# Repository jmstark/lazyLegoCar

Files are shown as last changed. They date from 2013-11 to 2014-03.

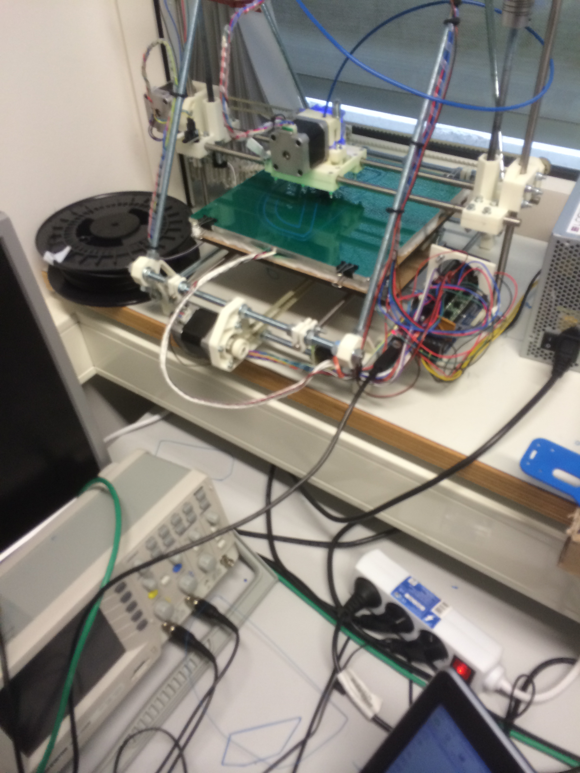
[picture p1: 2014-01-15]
Fotos/IMG_1469.JPG

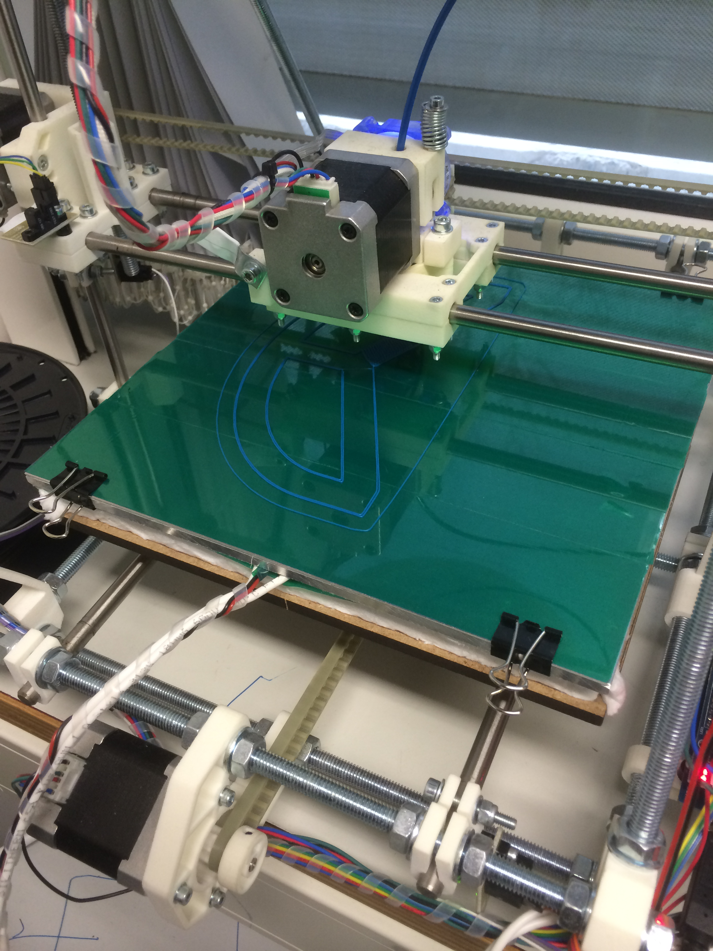
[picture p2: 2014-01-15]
Fotos/IMG_1471.JPG

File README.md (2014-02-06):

lazyLegoCar
===========

Lego car with basic collision avoidance/ path planning

Setup:
===========

Starting the car:
===========

Prerequisite:
Install the App "HelloWorld" (should be renamed in the future) on your smartphone: The compiled app is located in the github repository. The relative path is HelloWorld/bin/HelloWorld.apk. So either clone the git repository and pick the app from your file system, or download it directly from https://github.com/jmstark/lazyLegoCar/raw/master/HelloWorld/bin/HelloWorld.apk . Put the .apk-file on your smartphone and install it (Foreign app sources have to be enabled to allow this).
On your smartphone, the app is named "LegoCarControl".

If everything is compiled and in place (as is the case after the final presentation), to start the car you have to:

1. Turn on the battery.

2. Connect the ethernet port of the raspberry to your pc. Otherwise, it will not start. But you do not need to send anything over the ethernet connection.

3. The raspberry needs power over Micro-USB (a normal charging cable for a smartphone is sufficient). Plug it into your PC.

4. After about 30 seconds, the servo of the back laser should start to move, which indicates the start of the program. So you can connect now via WIFI.

5. On your smartphone, enable WIFI and connect to the WLAN with the SSID "lazyLegoCar". Then start the app.

6. In the app, there are two different modes of operation:

	-Direct control: Use the buttons to control the steering and driving direction of the car.

	-Path planning: Enter x- and y- coordinates and send it to the car. A positive x-Value means, the destination lies x centimeters to the right of the car. A positive y-Value means, the destination lies y centimeters in front of the car. After you send the coordinates, the car starts driving towards the final destination without your intervention. 

	NOTE: Since the car has no position sensors, all the calculations of the current position of the car rely on measurements and calibrations that have been done with full batteries. So if the car doesn't reach the exact destination, you can either use full batteries or change the constants in the sourcecode which determine the speed.

Compiling from source:
=================
It is recommended to do this on a Linux PC.

Clone the repository:
git clone github.com/jmstark/lazyLegoCar
 
Compiling code for arduino:
The SharpIR-Library needs to be installed in the Arduino IDE. You can find it in the "Library"-folder.
Load arduino/arduino.ino into the Arduino IDE. Compile and upload the code to the arduino.

Compiling code for raspberry pi:
Go into raspberry directory: cd raspberry.
A makefile is already supplied, so a simple "make" command starts the building process. The application is named "lazyLegoCar".
Either compile it on a Linux PC or on the raspberry itself. The program can be run on both, as long as there is a USB-connection from the desired platform to the Arduino board. A precompiled version + sourcecode is located on the raspberry under "~/lazyLegoCar/raspberry".

Compiling the App:
Import the project from the "HelloWorld" folder into eclipse (Android Development Tools and stuff has to be installed).
Eclipse is now able to recompile it.

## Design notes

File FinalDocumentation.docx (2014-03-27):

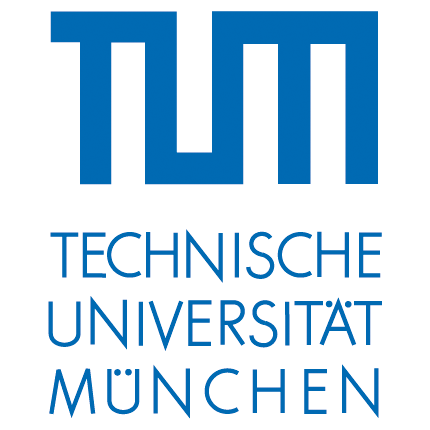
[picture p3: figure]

Fakultät für Informatik

Lehrstuhl Robotic und Embedded System

HW/SW Co-Design with a Lego Car

Final Project Documentation – Team Poorman’s Laser

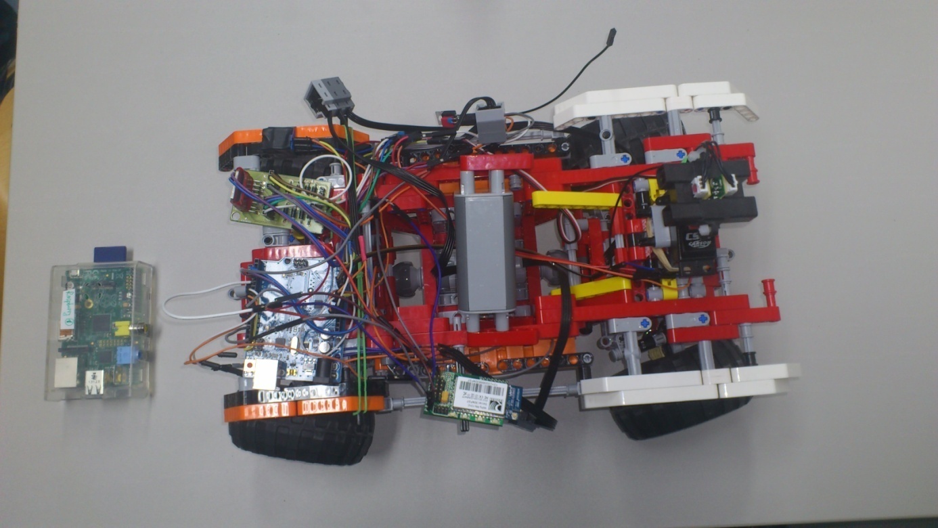
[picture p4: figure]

Daniel Collazion – Juri Kuhn – Josef Stark – Thomas Sennebogen – Viet Tiep Do

# Overview

Objective:

The Objective was to build an car that was able to drive autonomously and could be controlled wirelessly. We were given the accomplishments of our predecessing group, which included a lego car with two steering servo motors, two driving motors, an arduino board, a raspberry pi embedded system, a WiFly serial module for wireless communication, two infrared distance sensors mounted together on a servo motor and the required hardware connections between all these components. We also got the sourcecode for a would-be autonomous path planning system. Due to the fact that the previous group did not implement any self-localization mechanism, they tried to implement a simple algorithm which avoids obstacles but follows no special path. It was supposed to scan the environment while standing still, then drive around obstacles until the end of the scanned area is reached, just to stop and scan the environment again, repeating this over and over. Unfortunately, they used ROSserial as library for communication between the raspberry and the arduino board. As the implementation of Rosserial was/is not yet in a usable state on the raspberry, they were not able to test their code. All of this can be read in their documentation.

Goals:

A) Enable basic collision avoidance without path planning

B) Enable collision avoidance with path planning and wireless control via WIFI over an android app.

The beginnings:

We thought, that it would make much sense to build on the work of the previous group, so that we would not have to reimplement everything. So we pulled a current ROSserial release, compiled everything and tried everything out, hoping that the current ROSserial implementation would allow our car to drive. But as - even after trying out many dirty hacks - it was not possible to get it to work, we decided that it would not make much sense to put more energy into this unpromising task of reviving the old code, considering that both a) reimplementing a basic collision avoidance algorithm with a different protocol and b) implementing a simple binary protocol via serial pipes did seem not that difficult. We also estimated, that even in the worst case, the arduino board alone (without help from the raspberry), would provide enough computing power (16 MHz) and memory (2 KiB RAM, 16 KiB ROM) for such a basic task, and also that the scanning could be done while driving, since a full spin of the IR-sensors only needs soundsoviel seconds, while they provide reliable range of 20 to about 90 centimeters and the car is driving with a maximum speed of only soundsoviel m/s. Only using the arduino for this first goal, we could avoid the hassle of having to enable communication between arduino and raspberry. (After the first goal was reached, we however enabled such a protocol since we then used the raspberry for path planning and wireless communication).

# 1. Initial situation

# 2. Wireless communication

# 2.1 The Android app

In order to control the car remotely using wireless communication we come to the idea of an Android app – name Poorman’s App. As the main purpose is providing a platform which is able to send simple command to control the car rather than developing a fancy or sophisticated one, we did not focus on the design of the app. The app has very simple and basic components that guaranties the usability and still cover all the functions needed to control the lego car. A screenshot of the main page of Poorman’s App can be seen below.

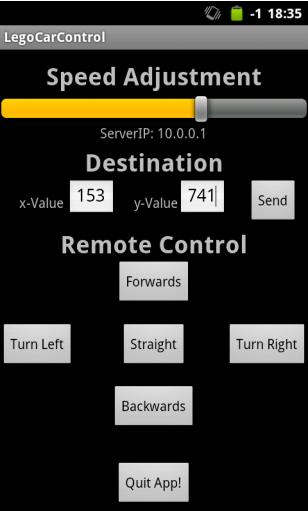
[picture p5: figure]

Picture 1: Screenshot of the Android app´

In the Speed Adjustment area, user can adjust the car’s speed he want. Speed is an important parameter in Path-planning mode. Notice that any speed-value smaller than 64 will be ignored. The maximal value is 255.

The app supports two modes:

- Basic mode: User can drive the car forwards or backwards by pressing and holding Forwards- or Backwards-Button. Leaving the buttons make the car stop. The buttons Turn Left, Straight and Turn Right steer the wheel-position to the left, straight or to the right correspondently. That means user should set the steering firstly and then drive the car backwards or forwards as changing the direction when the car is driving is not allowed. Besides, there are only three wheel-positions given: straight, 45° degree to the left and 45° degree to the right.

- Path-finding mode: The Lego car is also able to drive to a given position, which can be specified by giving its coordination. User type the x-value and y-value in the text box and press Send-button to trigger the command. As the car receives this command, it will consider its actual position as null-position und drive itself to the desired position. Based on the car speed, curve-radius of its wheel we develop an simple algorithm that automatically calculate the car’s driving path to the reachable given position (See chapter 4 for further information). The most important parameter that decides the accuracy is the speed and to keep the car in constant speed enough power should be provided.

The communication between the app and lego car bases on the technology of socket. A socket address is the combination of an IP address and a port number, much like one end of a telephone connection is the combination of a phone number and a particular extension. We connect a Wifi-usb adapter, which provides a local wifi network, to the Raspberry Pi. A server is setup on the Raspberry, opens a port for communication. The app is basically a client and it can send to or receives data from the server. More details in coding can be found in the appendix.

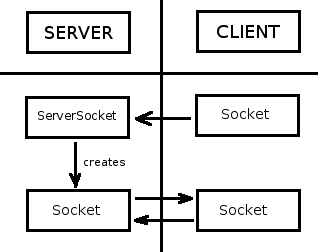
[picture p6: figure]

Picture 2: Server-client principle

# 2.2 Raspberry Pi

Text

# 3. Added Features

Text

# 4. Path planing

Text

# 5. Conclusion

Text

# 6. Appendix

Arduino Code

Code here

Raspberry Code

Code here

Android Code

In order to install the PoormanApp we need several files which can be found in the project folder. Below only the content of three important files are shown. Those are the MainActivity.java, activity_main.xml and the Manifest.xml. The MainActivity.java contains the core function of the app, which handle the input data provides by the users and send this information to Rasperry Pi. The activity_main.xml is simple the design of the app and the Manifest.xml file presents the important configuration.

• MainActivity.java

package com.example.poormanapp;

import java.io.DataOutputStream;

import java.io.IOException;

import java.io.OutputStreamWriter;

import java.io.PrintWriter;

import java.net.Socket;

import java.net.UnknownHostException;

import android.app.Activity;

import android.graphics.Color;

import android.graphics.PorterDuff;

import android.graphics.drawable.ClipDrawable;

import android.graphics.drawable.Drawable;

import android.graphics.drawable.LayerDrawable;

import android.os.Bundle;

import android.view.MotionEvent;

import android.view.View;

import android.view.View.OnClickListener;

import android.view.animation.Animation;

import android.view.animation.AnimationUtils;

import android.widget.Button;

import android.widget.EditText;

import android.widget.ProgressBar;

import android.widget.SeekBar;

import android.widget.SeekBar.OnSeekBarChangeListener;

import android.widget.TextView;

public class MainActivity extends Activity {

Button mainButton;

Button leftButton;

Button rightButton;

Button driveButton;

Button backButton;

Button straightButton;

Button sendButton;

Animation buttonEffect;

Drawable d;

public static final int ServerPort = 4359; //ServerPort is free to choose

public static final String ServerIP = "10.0.0.1"; //ServerIP should be changed according to device

Socket socket;

PrintWriter printWriter;

DataOutputStream DOS;

String xWert;

String yWert;

EditText xInput;

EditText yInput;

@Override

protected void onCreate(Bundle savedInstanceState) {

super.onCreate(savedInstanceState);

setContentView(R.layout.activity_main);

final TextView reading = (TextView) findViewById(R.id.reading);

SeekBar seekBar = (SeekBar)findViewById(R.id.seekbar);

seekBar.setMax(255);

xInput = (EditText) findViewById(R.id.xvalue);

yInput = (EditText) findViewById(R.id.yvalue);

if (ServerIP != null)

reading.setText("ServerIP: "+ServerIP);

try {

socket = new Socket(ServerIP, ServerPort);

printWriter = new PrintWriter(new OutputStreamWriter(socket.getOutputStream()));

if (socket.isConnected())

reading.setText("Connection succeeds!");

else

reading.setText("Connection fails!");

seekBar.setOnSeekBarChangeListener(new OnSeekBarChangeListener() {

@Override

public void onStopTrackingTouch(SeekBar seekBar) {

}

@Override

public void onStartTrackingTouch(SeekBar seekBar) {

}

@Override

public void onProgressChanged(SeekBar seekBar, int progress, boolean fromUser) {

reading.setText("Speed "+progress+ " cm/s");

if(progress <= 64){

seekBar.setBackgroundColor(Color.RED);

}else{

seekBar.setBackgroundColor(Color.GREEN);

}

printWriter.print("Speed " + Integer.toString(progress));

printWriter.flush();

}

});

buttonEffect = AnimationUtils.loadAnimation(getApplicationContext(), R.anim.button_effect);

mainButton = (Button) findViewById(R.id.button_main);

mainButton.setOnClickListener(new OnClickListener(){

@Override

public void onClick(View v){

mainButton.startAnimation(buttonEffect);

printWriter.print("Exit");

printWriter.flush();

try {

socket.close();

} catch (IOException e) {

e.printStackTrace();

}

finish();

}

});

straightButton = (Button) findViewById(R.id.button_straight);

leftButton = (Button) findViewById(R.id.button_left);

rightButton = (Button) findViewById(R.id.button_right);

driveButton = (Button) findViewById(R.id.button_forward);

backButton = (Button) findViewById(R.id.button_backward);

sendButton = (Button) findViewById(R.id.button_send);

d = (Drawable) mainButton.getBackground();

sendButton.setOnClickListener(new OnClickListener(){

@Override

public void onClick(View v){

sendButton.startAnimation(buttonEffect);

xWert = xInput.getText().toString();

yWert = yInput.getText().toString();

String destination = "Destination " + (xWert.equals("") ? "0" : xWert) + " " + (yWert.equals("") ? "0" : yWert);

printWriter.print(destination);

printWriter.flush();

}

});

leftButton.setOnClickListener(new OnClickListener(){

@Override

public void onClick(View v){

leftButton.setBackgroundColor(Color.CYAN);

rightButton.setBackgroundDrawable(d);

straightButton.setBackgroundDrawable(d);

printWriter.print("Left");

printWriter.flush();

}

});

straightButton.setOnClickListener(new OnClickListener(){

@Override

public void onClick(View v){

straightButton.setBackgroundColor(Color.RED);

rightButton.setBackgroundDrawable(d);

leftButton.setBackgroundDrawable(d);

printWriter.print("Straight");

printWriter.flush();

}

});

rightButton.setOnClickListener(new OnClickListener(){

@Override

public void onClick(View v){

rightButton.setBackgroundColor(Color.GREEN);

leftButton.setBackgroundDrawable(d);

straightButton.setBackgroundDrawable(d);

printWriter.print("Right");

printWriter.flush();

}

});

driveButton.setOnTouchListener(new View.OnTouchListener() {

@Override

public boolean onTouch(View v, MotionEvent event) {

if(event.getAction() == MotionEvent.ACTION_DOWN) {

driveButton.setBackgroundColor(Color.BLUE);

printWriter.print("Forwards");

printWriter.flush();

}

else if(event.getAction() == MotionEvent.ACTION_UP)

{

driveButton.setBackgroundDrawable(d);

printWriter.print("Stop");

printWriter.flush();

}

return true;

}

});

backButton.setOnTouchListener(new View.OnTouchListener() {

@Override

public boolean onTouch(View v, MotionEvent event) {

if(event.getAction() == MotionEvent.ACTION_DOWN){

backButton.setBackgroundColor(Color.YELLOW);

printWriter.print("Backwards");

printWriter.flush();

}

else if(event.getAction() == MotionEvent.ACTION_UP)

{

backButton.setBackgroundDrawable(d);

printWriter.print("Stop");

printWriter.flush();

}

return true;

}

});

} catch (UnknownHostException e) {

e.printStackTrace();

} catch (IOException e) {

e.printStackTrace();

}

}

public void setProgressBarColor(ProgressBar progressBar, int newColor){

LayerDrawable ld = (LayerDrawable) progressBar.getProgressDrawable();

ClipDrawable d1 = (ClipDrawable) ld.findDrawableByLayerId(R.id.progressshape);

d1.setColorFilter(newColor, PorterDuff.Mode.SRC_IN);

}

}

• activity_main.xml

<RelativeLayout xmlns:android="http://schemas.android.com/apk/res/android"

xmlns:tools="http://schemas.android.com/tools"

android:layout_width="match_parent"

android:layout_height="match_parent"

android:orientation="vertical"

tools:context=".MainActivity" >

<TextView

android:id="@+id/textView2"

android:layout_width="wrap_content"

android:layout_height="wrap_content"

android:textSize="@dimen/font_size"

android:layout_marginTop="10dp"

android:layout_centerHorizontal="true"

android:text="@string/SpeedSetting" />

<SeekBar

android:id="@+id/seekbar"

android:layout_width="fill_parent"

android:layout_height="wrap_content"

android:layout_alignParentRight="true"

android:layout_below="@+id/textView2"

android:layout_margin="1dp" />

<TextView

android:id="@+id/reading"

android:layout_width="wrap_content"

android:layout_height="wrap_content"

android:layout_below="@+id/seekbar"

android:layout_centerHorizontal="true" />

<TextView

android:id="@+id/textView3"

android:layout_width="wrap_content"

android:layout_height="wrap_content"

android:textSize="@dimen/font_size"

android:layout_marginTop="100dp"

android:layout_centerHorizontal="true"

android:text="@string/Destination" />

<EditText

android:id="@+id/xvalue"

android:layout_width="50dp"

android:layout_height="40dp"

android:layout_marginTop="135dp"

android:layout_centerHorizontal="true"

android:layout_alignParentLeft="true"

android:layout_marginLeft="70dp"

android:inputType="numberDecimal|numberSigned"/>

<EditText

android:id="@+id/yvalue"

android:layout_width="50dp"

android:layout_height="40dp"

android:layout_marginTop="135dp"

android:layout_centerHorizontal="true"

android:layout_alignParentLeft="true"

android:layout_marginLeft="185dp"

android:inputType="numberDecimal|numberSigned"/>

<TextView

android:id="@+id/xValue"

android:layout_width="wrap_content"

android:layout_height="wrap_content"

android:layout_marginTop="150dp"

android:layout_centerHorizontal="true"

android:layout_alignParentLeft="true"

android:layout_marginLeft="20dp"

android:text="@string/xValue" />

<TextView

android:id="@+id/yValue"

android:layout_width="wrap_content"

android:layout_height="wrap_content"

android:layout_marginTop="150dp"

android:layout_centerHorizontal="true"

android:layout_alignParentRight="true"

android:layout_marginRight="135dp"

android:text="@string/yValue" />

<TextView

android:id="@+id/textView1"

android:layout_width="wrap_content"

android:layout_height="wrap_content"

android:textSize="@dimen/font_size"

android:layout_marginTop="185dp"

android:layout_centerHorizontal="true"

android:text="@string/LazyLegocar_Control" />

<Button

android:id="@+id/button_send"

android:layout_width="wrap_content"

android:layout_height="wrap_content"

android:layout_centerHorizontal="true"

android:layout_alignParentRight="true"

android:layout_marginRight="10dp"

android:layout_marginTop="135dp"

android:text="@string/Send" />

<Button

android:id="@+id/button_forward"

android:layout_width="wrap_content"

android:layout_height="wrap_content"

android:layout_centerHorizontal="true"

android:layout_marginTop="220dp"

android:text="@string/Forwards" />

<Button

android:id="@+id/button_backward"

android:layout_width="wrap_content"

android:layout_height="wrap_content"

android:layout_centerHorizontal="true"

android:layout_marginTop="350dp"

android:text="@string/Backwards" />

<Button

android:id="@+id/button_right"

android:layout_width="wrap_content"

android:layout_height="wrap_content"

android:layout_centerHorizontal="true"

android:layout_alignParentRight="true"

android:layout_marginTop="285dp"

android:text="@string/Right" />

<Button

android:id="@+id/button_straight"

android:layout_width="wrap_content"

android:layout_height="wrap_content"

android:layout_centerHorizontal="true"

android:layout_marginTop="285dp"

android:text="@string/Straight" />

<Button

android:id="@+id/button_left"

android:layout_width="wrap_content"

android:layout_height="wrap_content"

android:layout_alignParentLeft="true"

android:layout_marginTop="285dp"

android:text="@string/Left" />

<Button

android:id="@+id/button_main"

android:layout_width="wrap_content"

android:layout_height="wrap_content"

android:layout_centerHorizontal="true"

android:layout_marginTop="430dp"

android:text="@string/Exit" />

</RelativeLayout>

• Manifest.xml

<?xml version="1.0" encoding="utf-8"?>

<manifest xmlns:android="http://schemas.android.com/apk/res/android"

package="com.example.poormanapp"

android:versionCode="1"

android:versionName="1.0" >

<uses-sdk

android:minSdkVersion="8"

android:targetSdkVersion="18" />

<uses-permission android:name="android.permission.INTERNET" >

</uses-permission>

<uses-permission android:name="android.permission.ACCESS_NETWORK_STATE" >

</uses-permission>

<application

android:allowBackup="true"

android:debuggable="true"

android:icon="@drawable/ic_launcher"

android:label="@string/app_name"

android:theme="@style/AppTheme" >

<activity

android:screenOrientation="portrait"

android:name="com.example.poormanapp.MainActivity"

android:label="@string/app_name" >

<intent-filter>

<action android:name="android.intent.action.MAIN" />

<category android:name="android.intent.category.LAUNCHER" />

</intent-filter>

</activity>

</application>

</manifest>

Fotos, Videos, Presentation, Repository and further information can be found on this site:

www.github.com/jmstark/lazylegocar

Final Project Documentation

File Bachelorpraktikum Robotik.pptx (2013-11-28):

## Hardware / Software Co-Design with a LEGO car WS 2013/1014

Poor - Man’s - Laser - Car

## current state

- driving
- steering
- obstacle recognition

## problems

- unprecise sensor data
- communication with WiFly device

## plans

- obstacle avoidance
- wifi connection
- control with android app

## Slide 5

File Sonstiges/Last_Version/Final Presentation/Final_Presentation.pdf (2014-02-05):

Poorman's Laser | 1

# Final Presentation

Hardware/Software Co-Design with a Lego Car

Group: Poorman‘s Laser

Daniel Collaziol
Juri Kuhn
Josef Stark
Thomas Sennebogen
Viet Tiep Do

05.02.2014

# Presentation Highlights

- Introduction
- Progress until midterm presentation
- Objectives after midterm presentation
- Known & Remaining problems
- Solutions and Improvements
- Results
- Experience
- Conclusion
- Additional information & documentation

### 1. Introduction

Initial Components

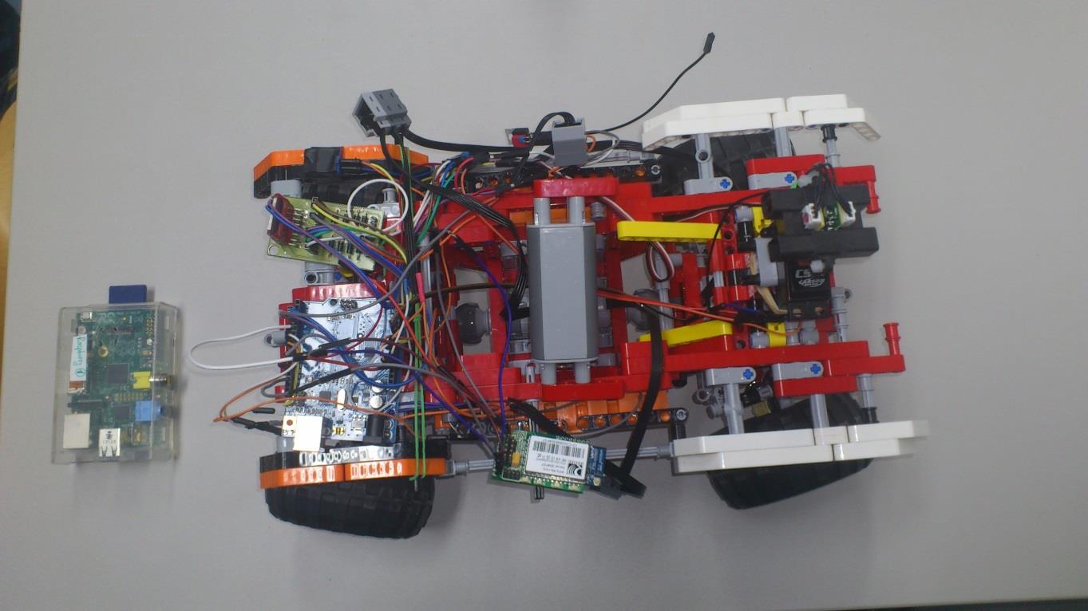
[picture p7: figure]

Lego Car

Arduino Board

Raspberry Pi

Engines

Infrared Sensor

Battery, Cables,H-Bridge..

Wifi-Module(which didnt
work...)

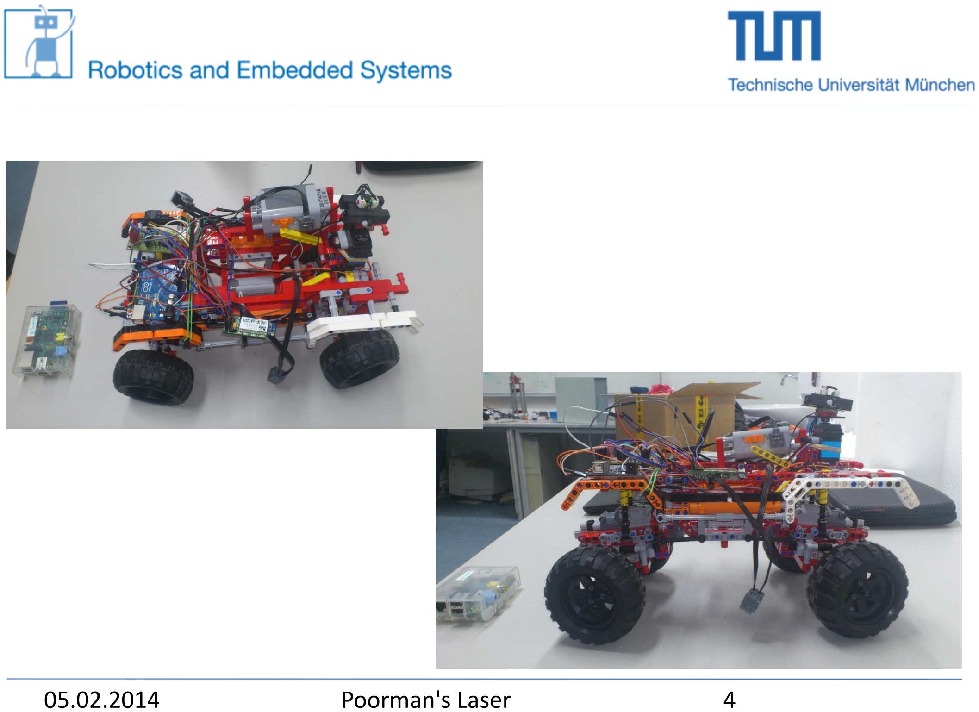
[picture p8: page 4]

05.02.2014 | Poorman's Laser | 4

### 2. Progress until Midterm presentation

- Development of a basic collision avoidance system
- The C.A. algorithm runs entirely on Arduino
- No path planning yet!

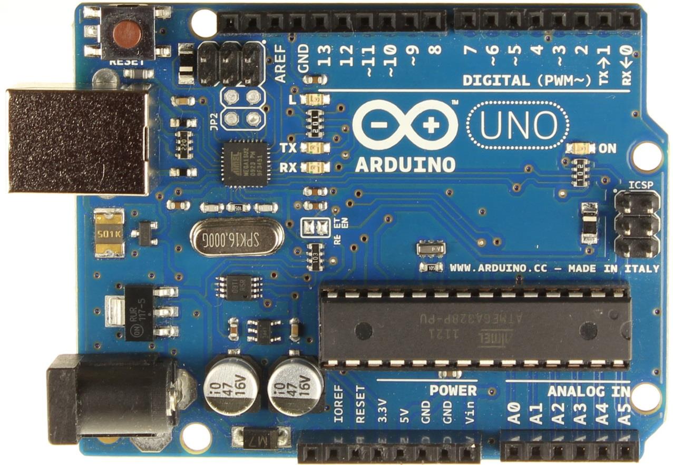
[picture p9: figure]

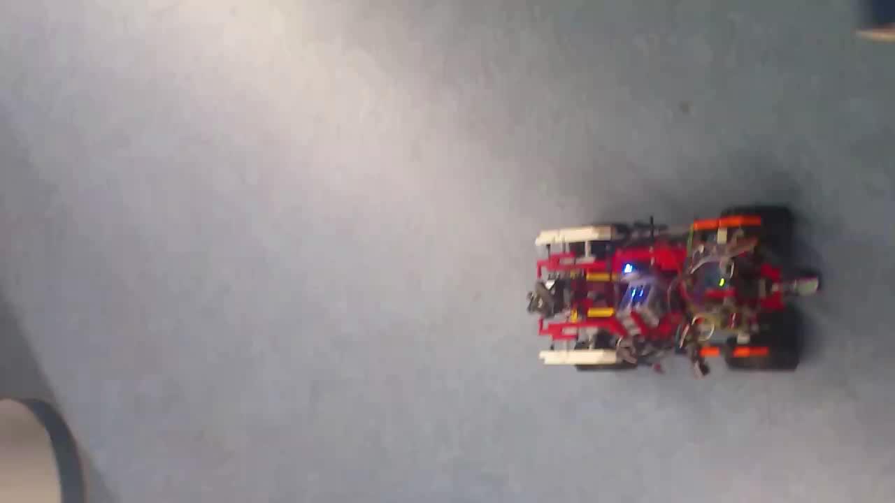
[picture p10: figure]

05.02.2014 | Poorman's Laser | 6

### 3. Objectives after midterm presentation

Added Features & Components:
- 5 more distance sensors
- Status LEDs
- Piezo speaker / sound feedback
- Calculations carried out by raspberrry!
- Path planning basic principles
- Remote control via Android application

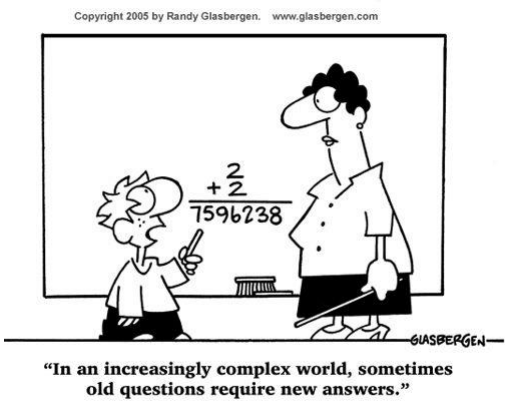
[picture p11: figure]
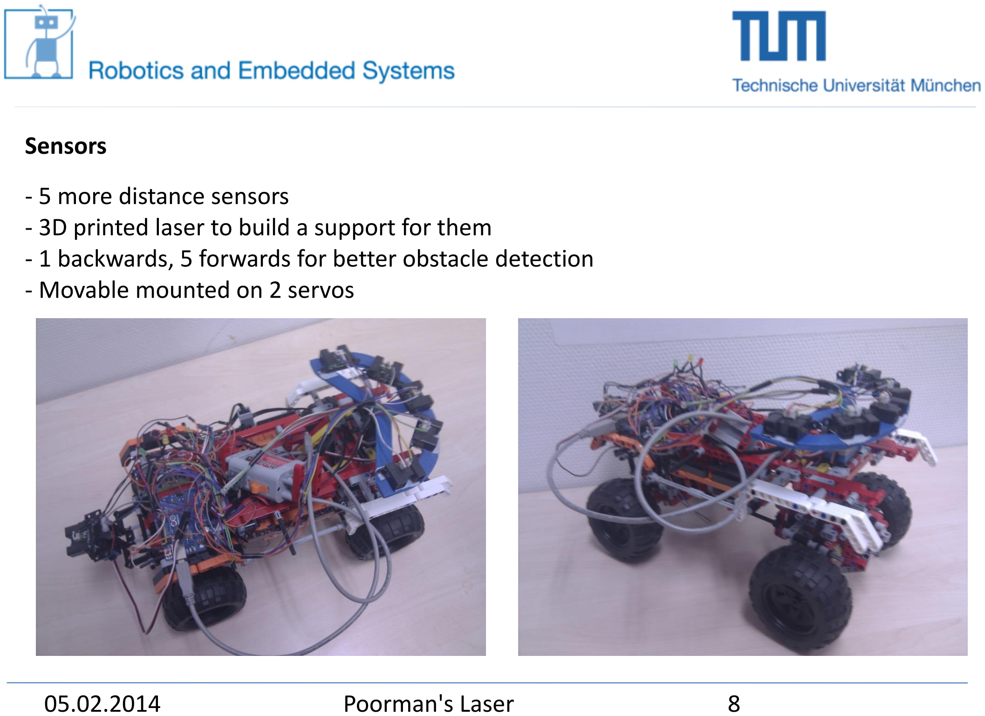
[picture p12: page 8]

Sensors

- 5 more distance sensors
- 3D printed laser to build a support for them
- 1 backwards, 5 forwards for better obstacle detection
- Movable mounted on 2 servos

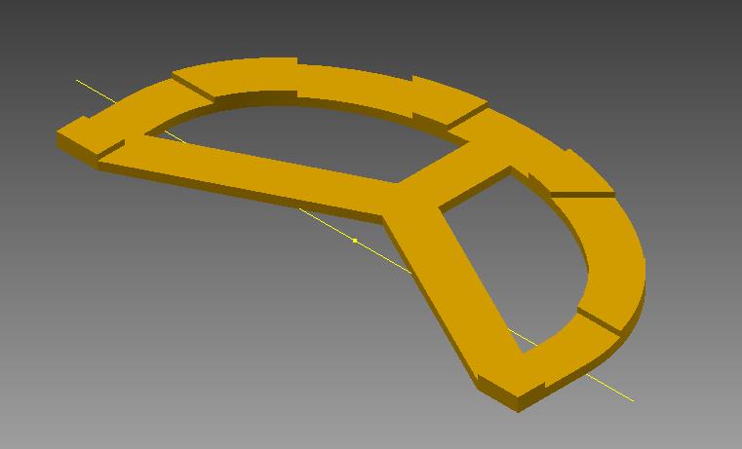
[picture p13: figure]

05.02.2014 | Poorman's Laser | 9

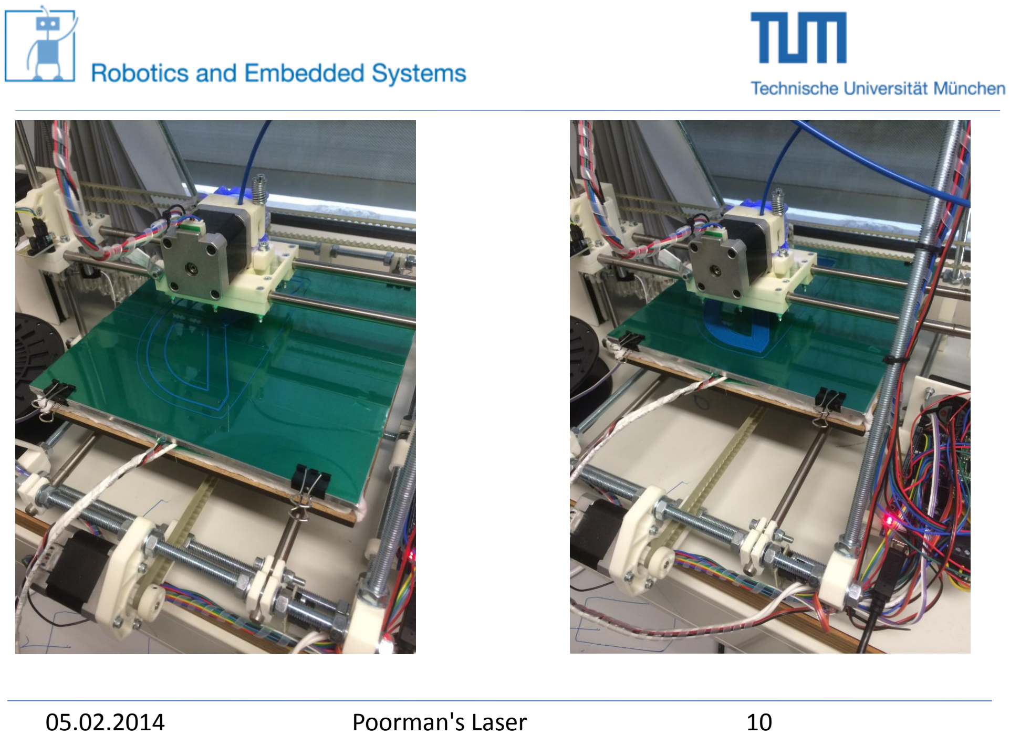
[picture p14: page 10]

05.02.2014 | Poorman's Laser | 10

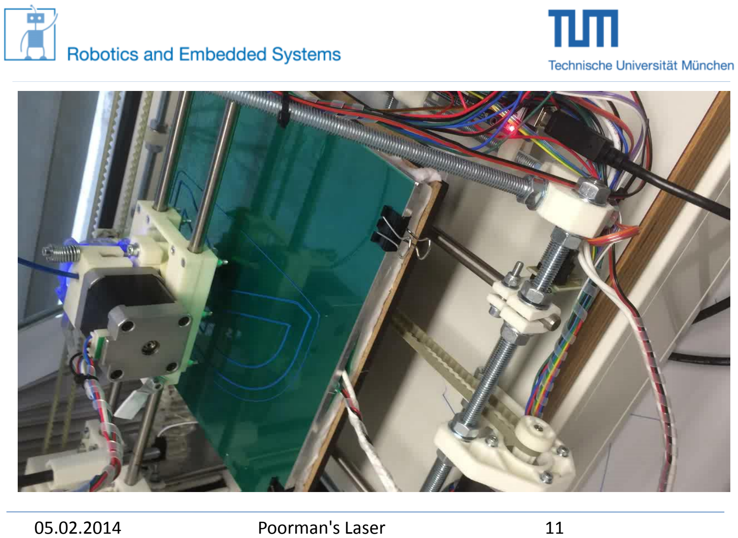
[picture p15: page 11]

05.02.2014 | Poorman's Laser | 11

Status LEDs & Piezo speaker

Visual signal with LEDs, which give feedback for three main states:
- Green → Power source connected
- Yellow → Android‘s App connected
- Red → Path planning mode activated

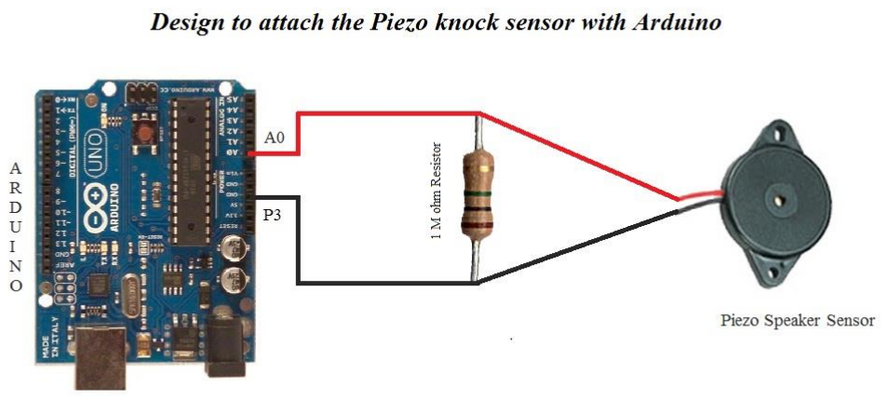
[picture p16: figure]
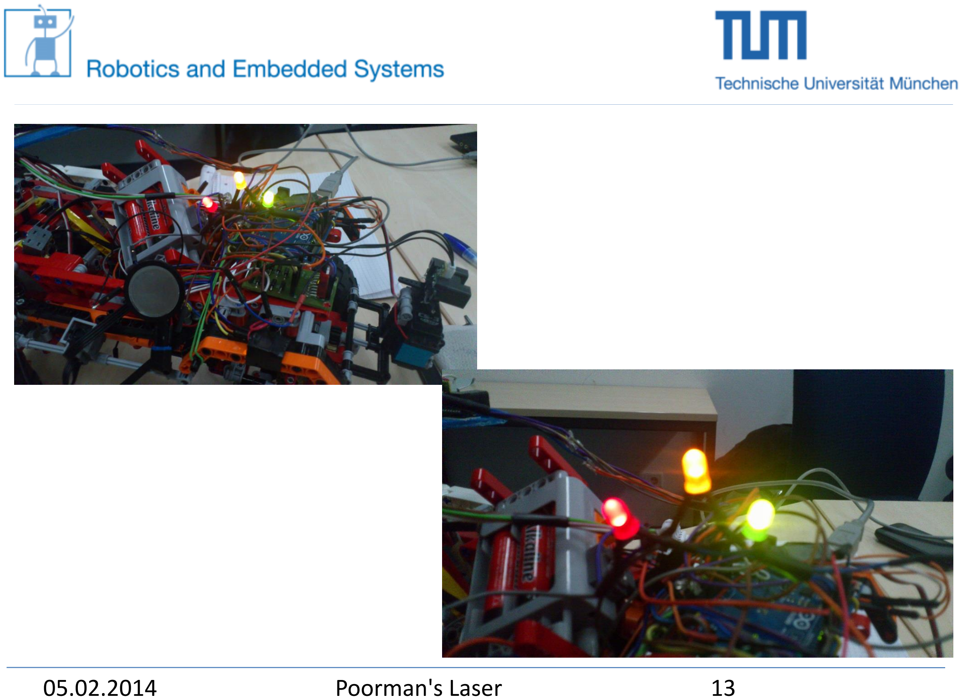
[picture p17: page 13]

05.02.2014 | Poorman's Laser | 13

Path Finding

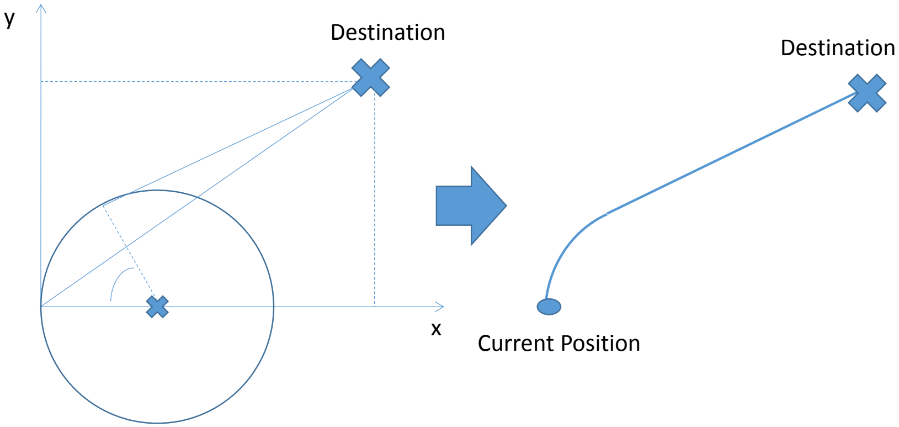
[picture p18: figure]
Destination; Current Position
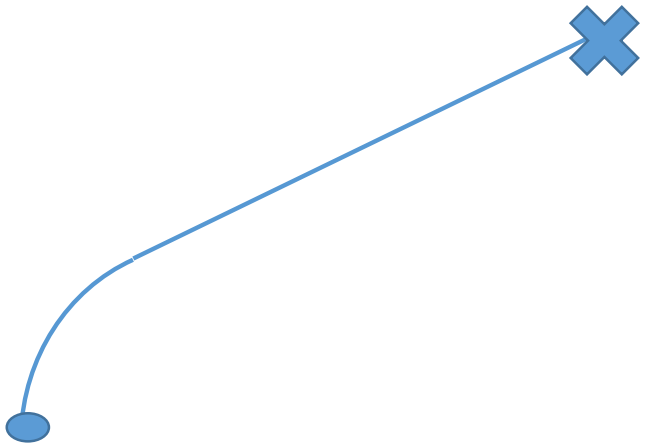
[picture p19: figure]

Algorithm‘s overall performance improvement

Path planning requires more memory
and better CPU throughput

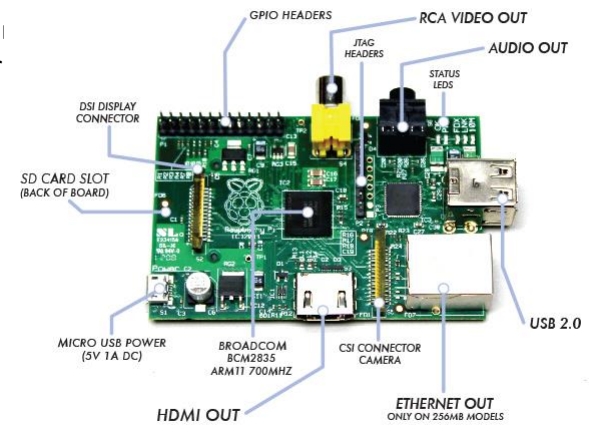
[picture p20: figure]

→ Main program now running on Raspberry Pi → Arduino acts as a simple intermediator between raw HW and Raspberry
→ Communication via binary numbers

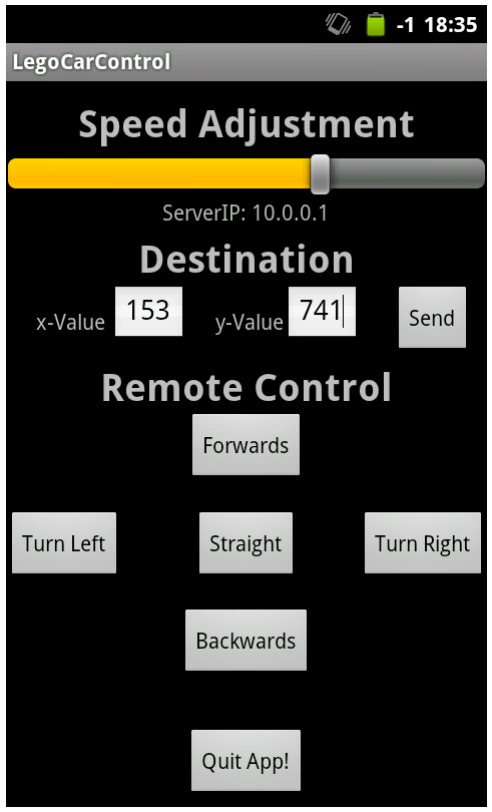
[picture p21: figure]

Android App

→ Supports two modes
→ Direct control
→ Path planning via cartesian coordinates → Path planning: Position given, speed adjustment → A simple client/server Java App

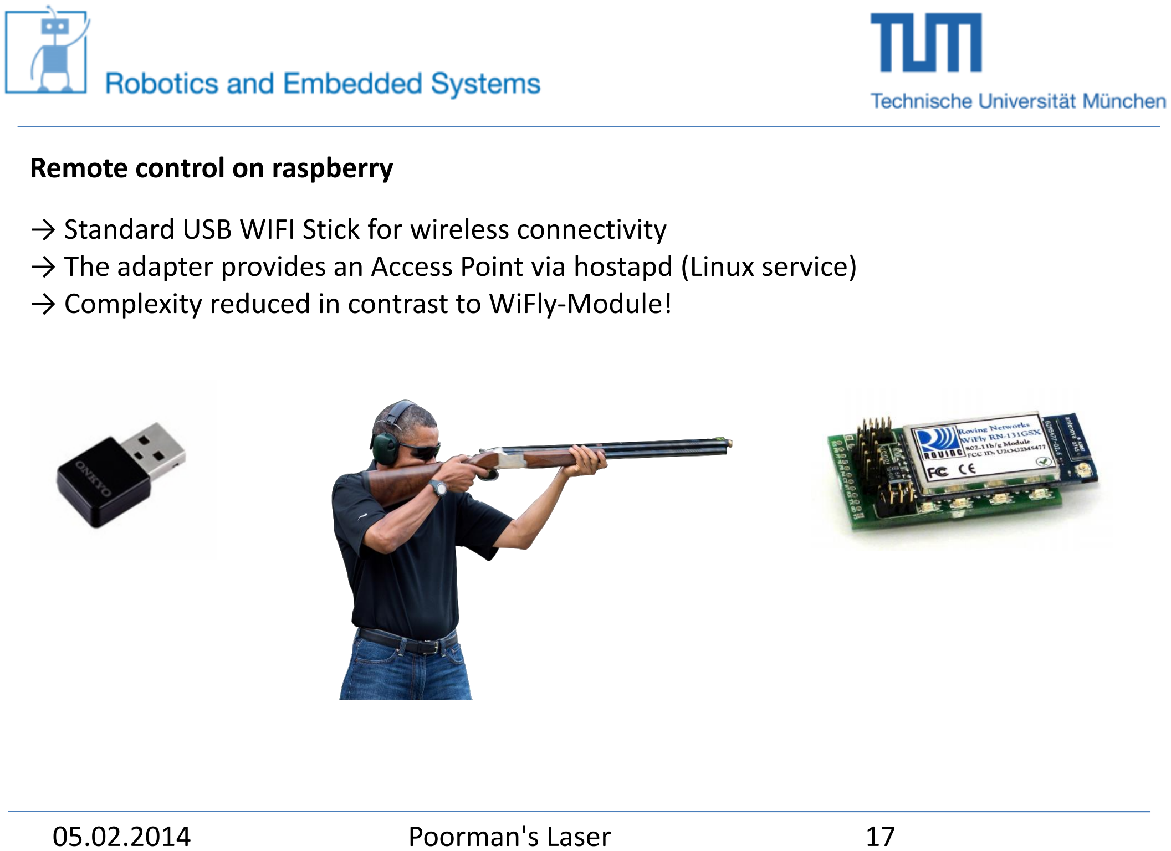
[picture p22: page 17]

Remote control on raspberry

→ Standard USB WIFI Stick for wireless connectivity
→ The adapter provides an Access Point via hostapd (Linux service) → Complexity reduced in contrast to WiFly-Module!

### 4. Known & Remaining Problems

→ Wifi-Module defects, using a Wlan-Module in combination with Raspberry as subtitution → Sensor‘s accuracy: inconsistent values
→ Path finding
→ Wires missing, missing contact...
→ Not enough power for sensors

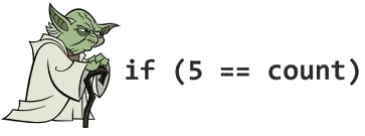
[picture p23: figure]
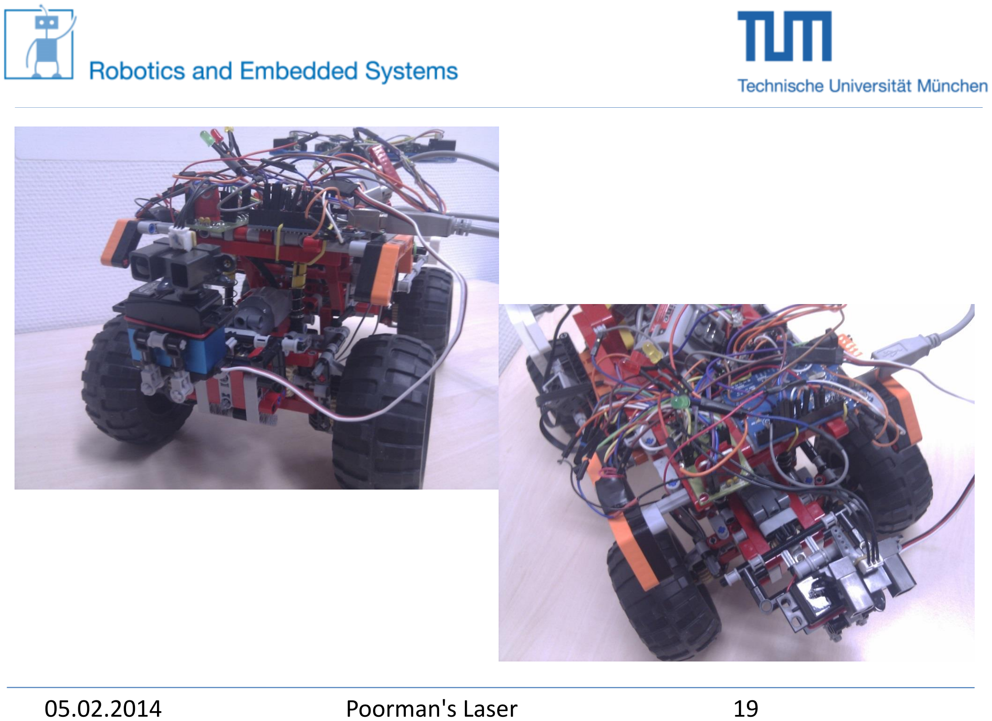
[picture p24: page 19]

05.02.2014 | Poorman's Laser | 19

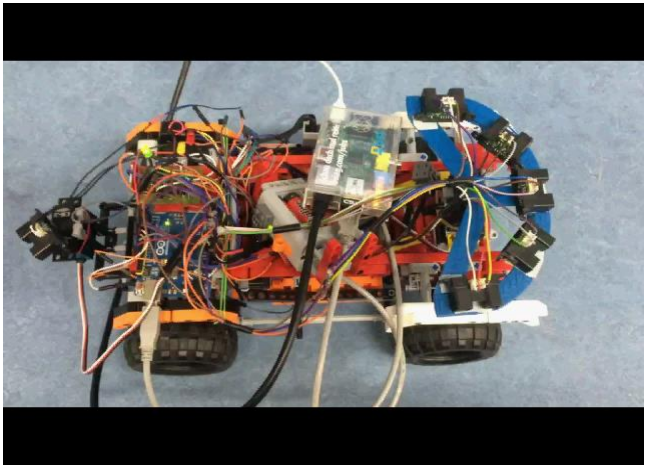
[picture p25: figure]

05.02.2014 | Poorman's Laser | 20

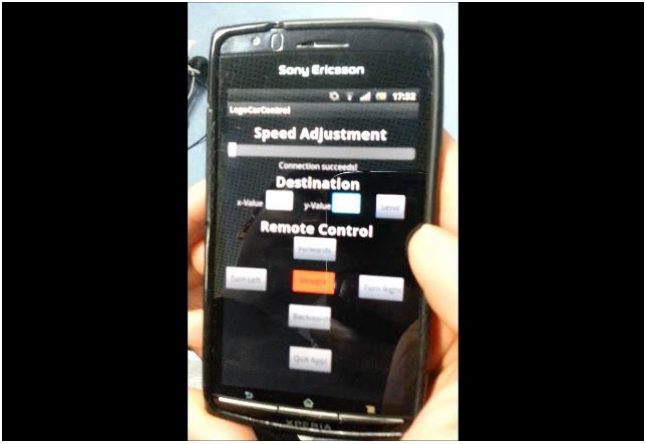
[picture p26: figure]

05.02.2014 | Poorman's Laser | 21

### 5. Experiences & some funny facts


→ Batteries for the car, pizzas for the drivers!
→ Almost 20 batteries needed!
→ Just don‘t leave Facebook open…
→ Ok ok… debugging messages are indeed important

### 6. Conclusion and potential of development

→ Android App control using accelerometer → Path planing with obstacle avoidance
→ Better wires
→ More battery power
→ Microcontroller with more pins


Additional information & documentation

## Check it out here: www.github.com/jmstark/lazyLegoCar


# Thank you for your attention!

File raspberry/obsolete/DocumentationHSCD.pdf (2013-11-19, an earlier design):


FAKULTÄT FUR INFORMATIK
DER TECHNISCHEN UNIVERSITAT MÜNCHEN

## HW/SW Co-Design with a LEGO car Final Project Documentation


### Team: Hannes Schulz, Sebastian Fischer, Lars Kipferl, John Chiotellis

## 1. Objective

The objective was to build an autonomously driving LEGO car by using an FPGA board and various sensors and actuators of our own choice. We were given the LEGO car and a budget of 100€ for hardware parts as well as some introduction into parallel computing, scheduling and other relevant topics. The design of the hardware and software was completely up to the students.
Because of that freedom, we decided to omit the original proposal of using the FPGA Board and switched to a design incorporating a Raspberry PI as a computing unit and an Arduino Uno Board (further denoted as Arduino) to communicate with sensors and actuators.

## 2. Overall Design

Our goal was to build a car that would be able to drive autonomously through any given environment and draw a map of that environment without bumping into obstacles. Furthermore, we wanted to add an object following behaviour to be able to follow other dynamic objects such as other LEGO cars. Due to the late arrival of hardware parts and the overall complexity of incorporating many different pieces of hardware into one working system, we had to make some adjustments to our original plans and ended up to design a simple, but extendable obstacle avoidance behaviour while driving around.

Our hardware design consists of three parts. First, we build our own “poor mans laser” sensor out of two infrared distance sensors (further denoted as IR sensor) mounted on top of a servo motor to be able to scan the environment for possible obstacles. As for the actuators, we used the original LEGO motors and servo motors to drive and steer respectively. Second, the Arduino is the single controller for the driving motors connected to a H-bridge as well as the servo motor that is responsible for steering. It also provides the values from the IR distance measure sensors. Last but not least, the Raspberry PI is connected over an USB cable to the Arduino and is responsible for the calculations regarding the driving behaviour using the values it gets from the IR sensors. As it sends the commands to control the car it constantly calculates its environment and avoids obstacles.
On the software side we decided to use the Robot Operating System (ROS) to be able to set up the cars driving logic as well as having an easy way of handling the sensor and actuator data of the whole system. Figure 1 shows the whole hardware design. The algorithm for driving autonomously is based on the potential field method for path planning and obstacle avoidance.

As for the car itself, we sticked with the original blueprints from LEGO, except that we did not use the upper chassis, since we needed space for all the cables and hardware parts (as you can see on the title page). This enables our car to drive over small, flat obstacles, which is quite useful as we discuss later on.


Figure 1

## 3. Hardware

We had two different demands on our hardware. First we needed a small but relatively powerful computer that is capable of doing the calculations for the potential field. And second a programmable microcontroller that in the best case is combined with an Analog-Digital-Converter (ADC) to interact with the IR sensors.
As the heart of our car we chose a Raspberry PI. The Raspberry PI is a very small and low cost ARM based computer, which has sufficient processing power to fulfill our needs.
Because of the IR sensors, that generate analogue values as well as the necessity to generate PWM signals to communicate with the servos and the H-Bridge we chose an Arduino microcontroller. This way we overcame the restrictions of the Raspberry PI: it is not capable of reading analogue inputs and can only produce one PWM output, but for our design we needed more. Also this platform is widely used and has a huge community, so a library for our IR sensors was already available. Another advantage of the Arduino is, that it can be programmed directly in C. Additionally, code can just be programmed over the USB port without the need for a special device for flashing the code onto the microcontroller. That makes the integration of the Arduino in our software framework easier.
As power supply, the battery pack that came with the provided LEGO car is used to power all components as well as the Raspberry PI. Therefore we needed a 5V output, but the power provided by the batteries was too much. So we built a voltage transformer according to the circuit diagram depicted in figure 2.


Figure 2

As a sensor to scan the environment we decided to build our own “poor mans laser” scanner consisting of a servo motor and two infrared range finders with a range of 20cm to 150cm, both mounted on top of the servo motor that rotates 180 degrees and back. The servo motor sweeps both rangefinders in steps of 10 degrees, giving us a 2 x 18 range scans of the environment to work with. The Problem with this setup is, that it scans the environment quite coarse and slow, leaving very small objects undetected and making path planning more difficult. Furthermore, we had to mount the IR sensors on top of the car, meaning that all obstacles smaller than the height of our IR sensor are a threat to our car, since they could be too big to drive over them but are not detectable by our setup even though the original car has a very solid 4 by 4 gear that is capable of driving over obstacles that are around the size of half the diameter of the wheels. All in all, it is very difficult to build a good distance sensor with limited resources at hand. But considering the fact that professional laser sensors cost several thousand euros it was the best solution for the given budget.
The complete circuit diagram with all components is depicted in figure 3. The Raspberry PI is not shown in this image, because it is connected to the Arduino over USB.
Initially it was also planned to use a webcam for object recognition and object following, but due to the lack of time and nonavailable Linux drivers we omitted this feature.


Figure 3

## 4. Software

On the Raspberry PI we installed Raspbian Wheezy which is a derivative of Debian and the Robot Operating System (ROS). ROS is a software framework for robot software development. It provides functionalities like message passing between different processes and hardware components, making communication of control commands and sensor callbacks a lot easier to handle. ROS is based on so called “nodes”, that publish or subscribe messages to or from topics. For our case we made 5 topics: radar_angle, radar_front, radar_back, directions_drive and directions_steer. The radar topics contain the values provided from the IR sensors and the angle in which they are pointing. The directions topics contain the desired action of the car, which is if the car should move for or backward and if it should steer in any direction.
That makes the whole software design very transparent, since it is possible to see what is going on in the system, using the various visualization tools provided by the ROS framework.
There is also a library available called rosserial that allows us to integrate the Arduino over a serial connection (USB) into the system, as it takes care of the communication. Rosserial is a protocol we have to run a separate node on the ROS system that communicates with the Arduino. This node is written in python and is shipped with the rosserial library. Besides the integration of the Arduino, ROS provides us with a series of predefined functions and libraries that make it a bit easier to implement complex algorithms.

For the Arduino a few libraries are available. To read the values from the Sharp IR distance sensors we use an existing library that returns us the readings from the sensors in centimeters. The Servo that rotates the distance sensors are controlled by the standard libraries that come with the Arduino IDE. The Lego servo motor from the powerfunction set is not controllable with this standard library because it runs on a custom PWM signal. Therefore we had to write our own library that depends on the Arduinos clock registers. Due to lack of documentation we had to try different frequencies to determine the right one. We did this with a simple forloop that runs through the different values. Once we found the right frequency we still had to try how the servo reacts to different inputs. The rest of the Arduino programming is very straightforward self explaining together with the comments in our code.

So all in all, the software setup of our projects consists of three ROS nodes, one representing the Arduino, which provides the data of our IR sensor and receives commands to drive and steer the car. This node publishes the current angle of the servo motor, the distance measurement of both IR sensors and receives two values, one for the motor and the other one for the servo for steering. These two values are provided by the node running on the Raspberry PI, which takes the IR sensor data to calculate where to drive based on the implemented logic, which is discussed in the algorithm section. To enable communicating between the Raspberry Pi and the Arduino the rosserial node is needed, that uses the USB connection to transfer data from one processor to the other. See figure 4 for the node setup.


Figure 4

## 5. Algorithm

Our algorithm for autonomous driving is based on the potential field method, which is a combination of path planning and obstacle avoidance. Due to the bad sensor information we omitted some of the original features of the potential field method.

The potential field method basically guides the robot safely from one point in space to another by treading the environment where the robot moves as a differentiable function and the robot as a point in this space, thus converting the problem of moving the robot into a gradient descent problem. This is done by building a virtual force that drives the robot towards its goal and away from any obstacles. The virtual force consists of an attractive force, which is the distance between the current position of the robot and its goal. Since we have not implemented any kind of selflocalization or mapping it is difficult to define a goal in space. That is why we defined our attractive force as a point directly in front of the robot, meaning the attractive force is pushing the robot straight forward all the time:

(1) | F (q) | 1|0) att | = (

The second part of the virtual force is the repulsive force, which originates from any obstacle scanned by our IR sensor while driving. The repulsive force is calculated by the derivative of a repulsive field equation that becomes weaker the further the robot is away from an obstacle, meaning that the distance to an obstacle has a direct influence on the strength of the repulsive force:

(2) | Frep (q) = krep ( | ) | if p(q)

1
p(q) −

1
p0

1
p (q)
2 | p(q)
q−qobstacle | ≤ p0

where krep

is a scaling factor, p(q) is the distance to the obstacle, p0

is the maximum distance
of influence of objects, q is the position of the robot in space (cartesian coordinates) andqobstacle is the position of the obstacle in space (also cartesian coordinates). Since we have no map, we only see our environment locally and therefore the robots position is always (0|0).
Since there could be more than one obstacle influencing the virtual force driving the robot, we decided to only use the closest obstacle to form the repulsive force to make it easier to decide where to drive.
The virtual force is the sum of the attractive and the repulsive force and should guide the robot safely through the environment:
(3) | F(q) = F (q) | F (q) att | + rep

A major problem for the potential field method are local minima. As the robot approaches concave structures, such as a corner in room, the robot gets several equidistant measurements from the range sensors, leaving the system trapped, because it will oscillate between different steer movements leaving the system trapped. To avoid this kind of behaviour, we implemented a backward movement, that If the robot approaches an obstacle and comes too close, it drives backwards and steers in the opposite direction, in the hope of getting out of the local minimum.

Another problem in our implementation is the way we handled the attractive force. Since we just want the robot to drive straight forward, the attractive force is always the same, which makes it more difficult to find a feasible set of parameters for the algorithm that works fine with the actual system. Furthermore, that also makes room for problems with small obstacles that lie directly in front of the robot. Since the robot is just pushed forward, a small obstacle in front of the robot that is measured only by the range scan that points in front of the robot would result in oscillating back and forth movement, since no force would push the robot sideways. This behaviour should also be avoided by the above described backward movement.

Another feature we added was that we do not look at obstacles that are over 40° or under -40° to the left and right sight respectively, because those obstacles do not threaten the robot while it is driving forward.

Also, to get a full scan of the environment our laser sensor needs several seconds, making realtime calculations of the repulsive forces somewhat difficult. Therefore our algorithm waits a full scan before driving and then drives for the period of one full scan, repeating that behaviour over and over again. This ensures a more robust obstacle avoidance, since we give our sensors enough time to collect the data we need for our calculations.

Despite the relative simplicity of the potential field method, it is quite difficult to find a good set of parameters that works well on the actual hardware system with all possible state space configurations the robot could encounter while driving in a real world environment. Even if our system does fail to avoid obstacles in some cases, it can manage quite a few situations without bumping into anything, making the drive logic of our system quite good.

## 6. Problems during the project

We lost a lot of time because of the missing documentation for the Lego powerfunction servo motor that runs at a custom PWM signal which is different from standard servo motors and therefore could not be used with the Arduinos standard libraries. We had no oszilloskop and even if we had one it would have taken us as much time to figure out how to use it as it took us to find the frequency by tryanderror.
Separating the work was also a hard task. Because we only had one car to test our functions on we had to coordinate numerous meetings and even then sometimes everybody wanted to test something on the car at the same time.
Unfortunately, the rosserial is still in an experimental state for architectures like the Raspberry PI. Despite trying several ROS distributions and hacking into every file, we were unable to get the rosserial node working on the Raspberry PI, so that we could not use it for presentation purposes. But since the rosserial package is still worked on actively, there should be fully working versions for the Raspberry PI in the near future. Due to the late delivery of the Raspberry PI, we encountered this problem far too late and were not able to write our own communication protocol. As we got it, we already centered our project around ROS and it would have been too much trouble to change this.

## 7. Conclusion

During our work on this project we had a few problems to solve. The issue with the powerfunctions servo for example forced us to engage in hardware level programming. But we learned a lot while we experiment with timers and hardware interrupts.
The, unfortunately unsolved, problem of rosserial showed us how complicated the integration of different systems. Future work could deal with this problem. Perhaps it is possible to connect the PI and the Arduino with I2C or SPI.
Besides this we have built a working car that is capable of recognizing and avoiding obstacles. As mentioned above there is also space for improvements and future development, for example regarding the algorithm. Improved sensor integration could result in the car being able to drive continuously without having to stop and wait for new data.

It is also possible to change the layout of the deployed sensors. More sensors could be placed in different heights or angles on the car or a camera could scan the whole environment around the car. The camera could also follow an object or a beacon.
In the end our car was able to drive autonomously using the potential field algorithm. The behavior of the car could be refined by mathematically estimating the optimal parameters for the algorithm (like the scaling factor). Furthermore, one could use/implement another communication protocol than rosserial and thus improve the data transmission speed and consequently the behavior of the car (detect obstacles faster). The whole project could be extended in many ways. One idea would be to create a map of the environment using the information about the obstacles positions from the infrared sensors (possibly SLAM). The map could then be transmitted to the cars of the other teams. These could explore the world, collect different kinds of data depending on their sensors and implement other algorithms (like object recognition) while following collisionfree paths.

## 8. Appendix

Code running on the Arduino in C++:

/************************************************ * Arduino code that handles communication with * all sensors, servos and motors.
*
* TUM SS 2013 Hardware/Software Co-Design * Lab Course (Supervisor: Kai Huang)
*
* AUTHORS: Sebastian Fischer, Hannes Schulz,
* | Lars Kipferl, John Chiotellis
***********************************************/

#include <ros.h>

#include <std_msgs/String.h> #include <std_msgs/Int32.h> #include <ServoLego.h>

#include <Servo.h>

#include <SharpIR.h>

// ros related variables
// nodehandle takes care of all the sending and receiving ros::NodeHandle nh;
// we are sending integer messages
std_msgs::Int32 angle_msg;
std_msgs::Int32 frontDist_msg;
std_msgs::Int32 backDist_msg;
// define publishers that publish the distance values with the topic // "radar" ros::Publisher angle_pub("radar_angle", &angle_msg);
ros::Publisher frontDist_pub("radar_front", &frontDist_msg);
ros::Publisher backDist_pub("radar_back", &backDist_msg);
Servo pmlServo; | // Servo for our "laser radar"
ServoLego steerServo; | // Lego Servo for steering
const int motorIN1 = 2; | // H-bridge leg 1 (pin IN1, dir1 PinA)
const int motorIN2 = 3; | // H-bridge leg 2 (pin IN2, dir2 PinA)
const int speedMotorA = 9; | // H-bridge EN_A
int angle; | // Fetch data from "laser radar" for ros_msg to publish
int frontDist;
int backDist;

// Create an instance of SharpIR, constructor is SharpIR(type, // analog_pin)
SharpIR backIR = SharpIR(GP2Y0A02YK,0); // back
SharpIR frontIR = SharpIR(GP2Y0A02YK,1); // front

/*************************************************** * this method sets the steering.
* 0 no steering

* 1 left
* 2 right
**************************************************/ void steer(int i) {
if(i == 1)
steerServo.left();
else if(i == 2)
steerServo.right();
else
steerServo.none();
}

/***************************************************************** * set the direction of the motor movement over the H-bridge
* 0 no driving
* 1 forward
* 2 backward
****************************************************************/ void drive(int i) {
if(i == 2) {
digitalWrite(motorIN1, LOW);
digitalWrite(motorIN2, HIGH); }
else if(i == 1) {
digitalWrite(motorIN1, HIGH); digitalWrite(motorIN2, LOW); }
else {
digitalWrite(motorIN1, LOW); digitalWrite(motorIN2, LOW); }
}

/************************************************************ * callback functions for the messages we have subscribed
* this method is called from nh.spinOnce() ***********************************************************/ // callback functions for subscribers
int drive_value;
void driveCallback(const std_msgs::Int32& drive_msg) { drive_value = drive_msg.data;
drive(drive_value);
}

int steer_value;
void steerCallback(const std_msgs::Int32& steer_msg) { steer_value = steer_msg.data;
steer(steer_value);
}

// now we can instantiate our subscribers
ros::Subscriber<std_msgs::Int32> drive_sub("directions_drive", &driveCallback); ros::Subscriber<std_msgs::Int32> steer_sub("directions_steer", &steerCallback);

void setup(){
//Serial.begin(57600);
steerServo.attach(7,8);
pmlServo.attach(12);
// Motor A
pinMode(motorIN1, OUTPUT); pinMode(motorIN2, OUTPUT); pinMode(speedMotorA, OUTPUT); // set motor to full speed digitalWrite(speedMotorA, HIGH); // initialise the nodehandler and nh.initNode();
// advertise our messages
nh.advertise(angle_pub);
nh.advertise(frontDist_pub); nh.advertise(backDist_pub);
// subscribe to directions topic nh.subscribe(drive_sub);
nh.subscribe(steer_sub);
}

/************************************************************** * This method is used to get the next step of our radar.
* The Radar turns in steps of 10 degrees.
* If 180 degrees are reached we jump back to 0 degrees. *************************************************************/ // store the current position
int currentPos = 0;

void sensorNext(){
if( currentPos < 180 ) {
currentPos+=10;
}
else {
currentPos = 0;
}
pmlServo.write(currentPos);

// prepare data and write to message angle = currentPos;
frontDist = frontIR.getData(); backDist = backIR.getData();
}

void loop(){
// let our radar trun
sensorNext();
// get message for publisher angle_msg.data = angle;
frontDist_msg.data = frontDist; backDist_msg.data = backDist; //Serial.println(angle_msg.data);

Serial.println(frontDist_msg.data); //Serial.println(backDist_msg.data); // now publish the data
angle_pub.publish(&angle_msg); frontDist_pub.publish(&frontDist_msg); backDist_pub.publish(&backDist_msg);
// this handles all the communication callbacks nh.spinOnce();
// we hae nothing to do for the subscriber because
// the defined callback is called from the nh.spinOnce() //wait 200ms
delay(200);
}

Self written LegoServo header file

#ifndef ServoLego_h

#define ServoLego_h

#include <inttypes.h>

// TICK_SIZE is the time between interrupts. This is essentially the // resolution // of the PWM we're able to create. This is also an average value,
// because other
// interrupts will affect the frequency of ours.
#define PWM_TICK_SIZE 50 // uS

// PWM_PERIOD is the period of the PWM we want to have
#define PWM_PERIOD 13000 // uS (20ms)

// This calculation is used to determine the 'reset' number for the // counter
#define PWM_TICK_PERIOD (int) (PWM_PERIOD / PWM_TICK_SIZE)

class ServoLego
{
public:
ServoLego();
void attach(int pin1, int pin2); // attach the given pin to the // next free channel, sets // pinMode, returns channel // number or 0 if failure
void left();
void right();
void none();
};

#endif

Corresponding C file that implements the ServoLego class

#include <avr/interrupt.h>

#include <avr/io.h>

#include <Arduino.h>

#include <ServoLego.h>

// Interrupt variables have to be defined as 'volatile' so that the // CPU always
// fetches them from RAM and doesn't get an incorrect value from cache volatile unsigned int timer2_counter = 0;
volatile unsigned int timer2_trigger_low = 500;
int level = 0;
int PWM_PIN1;
int PWM_PIN2;
// Timer2 overflow interrupt vector handler
// This is called every time timer 2 overflows (around every 50ms)
// This routine needs to be as small and short as possible so that we
// don't
// impact the rest of the Arduino by executing lots of code in the background ISR(TIMER2_OVF_vect) {
timer2_counter++;
if(timer2_counter == timer2_trigger_low) {
level = 0;
} else if(timer2_counter >= PWM_TICK_PERIOD) { timer2_counter = 0;
level = 1;
}
// Reset the timer2 counter so that it can count and overflow once // again
TCNT2 = 0;
}

ServoLego::ServoLego(){
TIMSK2 = 1<<TOIE2; // Timer 2 overflow interrupt enable TCNT2 = 0;
}

void ServoLego::attach(int pin1, int pin2){

PWM_PIN1 = pin1;
PWM_PIN2 = pin2;
pinMode(PWM_PIN1, OUTPUT); pinMode(PWM_PIN2, OUTPUT); }

void ServoLego::left(){

digitalWrite(PWM_PIN1, level); digitalWrite(PWM_PIN2, LOW);
}

void ServoLego::right(){

digitalWrite(PWM_PIN2, level); digitalWrite(PWM_PIN1, LOW);
}

void ServoLego::none(){

digitalWrite(PWM_PIN1, LOW); digitalWrite(PWM_PIN2, LOW);
}

Code running on the Raspberry PI (obstacle avoidance):

/*
Code for autonomous driving of LEGO Car. This Piece of code implements a basic obstacle avoidance behaviour while trying to drive forward.

TUM SS 2013 Hardware/Software Co-Design Lab Course
(Supervisor: Kai Huang)

AUTHORS: Lars Kipferl, Hannes Schulz, Sebastian Fischer, John Chiotellis

*/

#include "ros/ros.h"

#include "std_msgs/Int32.h" #include "math.h"

#include "float.h"

/// GLOBAL VARIABLES ///

int laser_angles[19] = {0}; // variables to store and manage // laser data
int laser_frontDist[19] = {320};
int laser_backDist[19] = {320};
int arraySize = 19;
int angle_index = 0;
int front_index = 0;
int back_index = 0;

double attForce[2]; // variable for attracting force double repForce[2]; // variable for repulsive force
double resForce[2]; | // variable for resulting force
bool drive_mode = false; | // switches between scanning and driving
int drive = 0; | // Integers for sending drive commands to arduino
int steer = 0;
double maxInf = 80.0; | // maximum distance (values over 80cm are
// ommited)

int scalFact = 27000; // scaling factor for calculating forces

double steerToRight = -0.01; | // parameter which decides when to
// steer right double steerToLeft = 0.01; // parameter which decides when to steer // to left

// Calculates the attractive force (currently set to fixed value) void calcAttForce() {
attForce[0] = 1.0;
attForce[1] = 0.0;
}

// Calculates the repulsive force by using laser_data
void calcRepForce() {
bool go_on = false; | // bool to decide wether other
// calculations are necessary

repForce[0] = 0;
repForce[1] = 0;
// Drive forward if no obstacles are found in a 40 to -40 degree // radius

for(int i=0;i<arraySize;i++) {
if(laser_angles[i] > -40 && laser_angles[i] < 40) { if(laser_frontDist[i] < maxInf) { // found obstacle? ...
go_on = true; | // ... then we need to calculate the
// repulsive force of it

break;
}
}
}
if(go_on) { | // obstacle found in 40 to -40 degree radius? >
// calculate repForce

// Search for nearest obstacle ...
double minDist = DBL_MAX;
int angle_ind;
for(int i=4;i<arraySize-4;i++) { // ... in 40 to -40 radius if(laser_frontDist[i] < minDist) {
minDist = laser_frontDist[i];
angle_ind = i;
}
}
// now calculate the repulsive force of the obstacle
double rad = laser_angles[angle_ind]*(M_PI/180); // need rad for // cos() and
// sin()
// function
double x = minDist*cos(rad); // cartesian coordinates of the // obstacle

double y = minDist*sin(rad);
if(minDist < maxInf && minDist != 0) {
repForce[0] = scalFact*((1/minDist)(1/maxInf))*(1/powf(minDist,2))*(x/minDist); repForce[1] = scalFact*((1/minDist)(1/maxInf))*(1/powf(minDist,2))*(y/minDist); }

}
}

// Calculates the resulting force by adding all attracting and // repulsive forces
void calcResForce() {
resForce[0] = attForce[0] + repForce[0];
resForce[1] = attForce[1] + repForce[1]; }

// Decide which motor controls to send
void discretize() {
if(resForce[1] <= steerToRight) { // if certain treshold is
// surpassed, steer right ... steer = 2;
} else if(resForce[1] > steerToLeft) { | // ... same for the left
| // side ...
steer = 1;
} else { // ... or just drive straight when nothing is happening steer = 0;
}
if(resForce[0] <= 0.0) { // if obstacles are too near, drive // backwards ...
drive = 2;
switch(steer) { // ... and steer in the opposite direction case(2): steer = 1;
break;
case(1): steer = 2;
break;
case(0): steer = 2;
}
} else {
drive = 1; // if the path ahead is clear, drive forward
}
ROS_INFO("steer: %d drive: %d", steer, drive); // outputs on
| // console which
| // driving commands
| // are sent
}

// Callback for servo motor (angle) subscriber
void laserAngleCallback(const std_msgs::Int32::ConstPtr& laserAngle_msg) {
// Fill laser data with one full scan, then begin overwriting old
// data
if(angle_index >= 19) {
angle_index = 0;
drive_mode = !drive_mode; // alternate between driving and // scanning for the duration of one // scan each
}
laser_angles[angle_index] = laserAngle_msg>data; laser_angles[angle_index] = 90; // angles should be represented in
| // righthandcoordinate system

angle_index++;
}

// Callback for front IR subscriber
void laserFrontDistCallback(const std_msgs::Int32::ConstPtr& laserFrontDist_msg) {
if(front_index >= 19) {
front_index = 0;
}
laser_frontDist[front_index] = laserFrontDist_msg>data; front_index++;
}

// Callback for back IR subscriber
void laserBackDistCallback(const std_msgs::Int32::ConstPtr& laserBackDist_msg) {
if(back_index >= 19) {
back_index = 0;
}
laser_backDist[back_index] = laserBackDist_msg>data; back_index++;
}

int main(int argc, char **argv)
{
// initialize node
ros::init(argc, argv, "potentialfield");

// nodehandler keeps track of wether the node is still running or // not
ros::NodeHandle n;

// set up subscriber to get data from arduino
ros::Subscriber angle_sub = n.subscribe("radar_angle", 1, laserAngleCallback); ros::Subscriber frontDist_sub = n.subscribe("radar_front", 1, laserFrontDistCallback); ros::Subscriber backDist_sub = n.subscribe("radar_back", 1, laserBackDistCallback);

// set up publisher to send data to arduino
ros::Publisher drive_pub = n.advertise<std_msgs::Int32>("directions_drive", 1); ros::Publisher steer_pub = n.advertise<std_msgs::Int32>("directions_steer", 1); // loop_rate determines how often processes are called in hertz
ros::Rate loop_rate(10);

int count = 0; // variable to count loop iterations (used
// internally by ros)
while(ros::ok())
{
// messages to be published by publisher std_msgs::Int32 drive_msg;
std_msgs::Int32 steer_msg;

// scan if not driving, drive when not scanning if(!drive_mode) {
calcAttForce();

calcRepForce();
calcResForce();
discretize();
drive_msg.data = 0; // sets the message data } else {
drive_msg.data = drive;
}
steer_msg.data = steer;

// publish messages to topic drive_pub.publish(drive_msg); steer_pub.publish(steer_msg);

// Pump Callbacks
ros::spinOnce();

// Wait (Depends on loop_rate) loop_rate.sleep();
++count;
}
return 0;
}

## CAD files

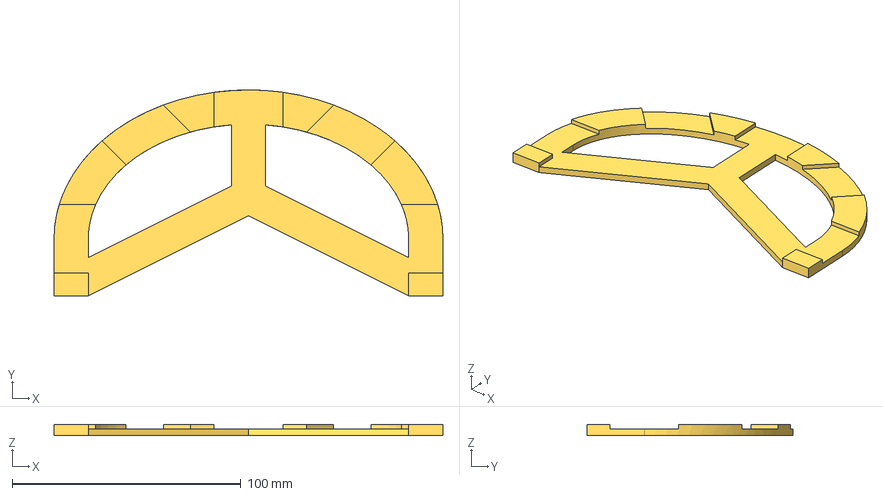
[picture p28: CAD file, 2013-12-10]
Laseraufbau/Laseraufbau.stp
170.0 x 89.9 x 5.00 mm

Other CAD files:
Laseraufbau/Laseraufbau.idw
Laseraufbau/Laseraufbau.ipt
Laseraufbau/Laseraufbau_ISO.idw

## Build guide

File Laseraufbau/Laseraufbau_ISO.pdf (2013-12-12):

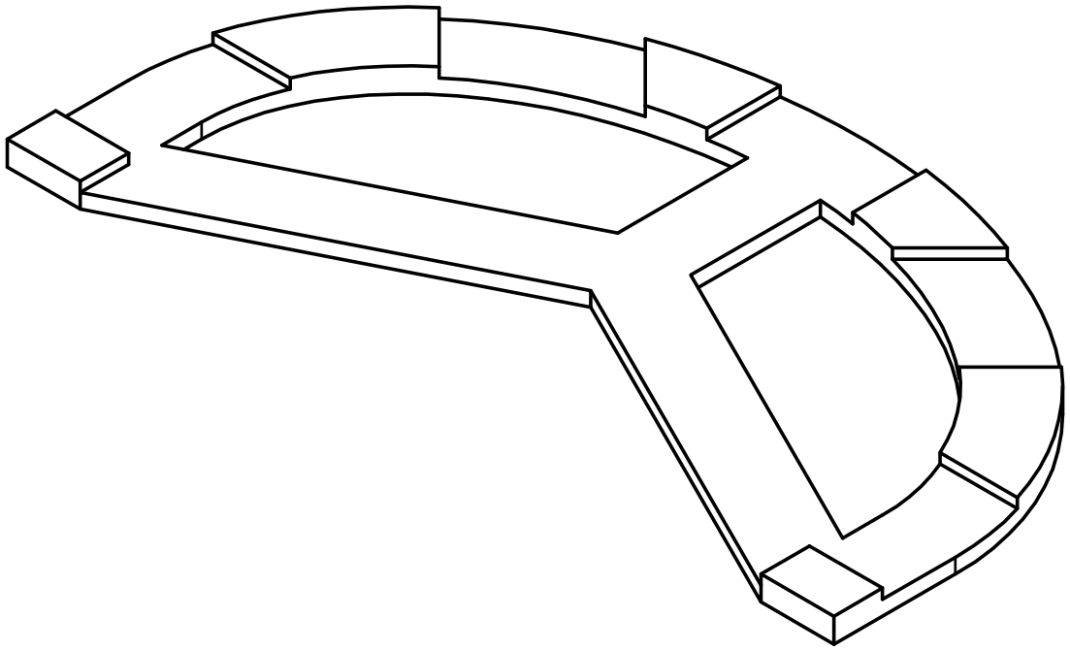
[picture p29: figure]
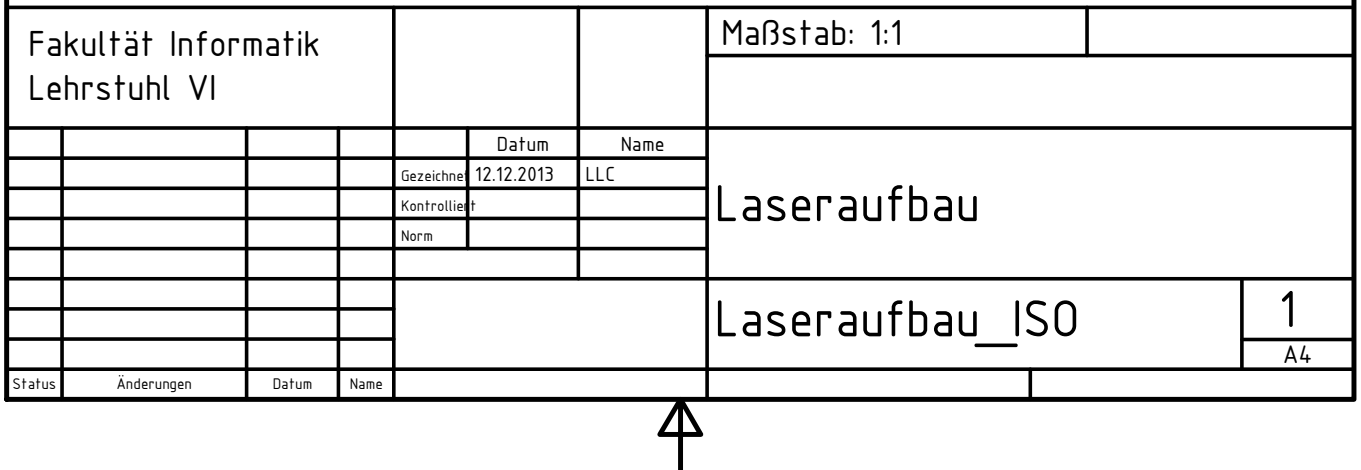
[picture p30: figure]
Laseraufbau; Laseraufbau_ISO; Status; |nderungen; Datum; Name; Gezeichnet; Kontrolliert; Norm; LLC; Fakultt Informatik Lehrstuhl VI; Mastab: 1:1

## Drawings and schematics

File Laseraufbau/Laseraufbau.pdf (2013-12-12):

11

22

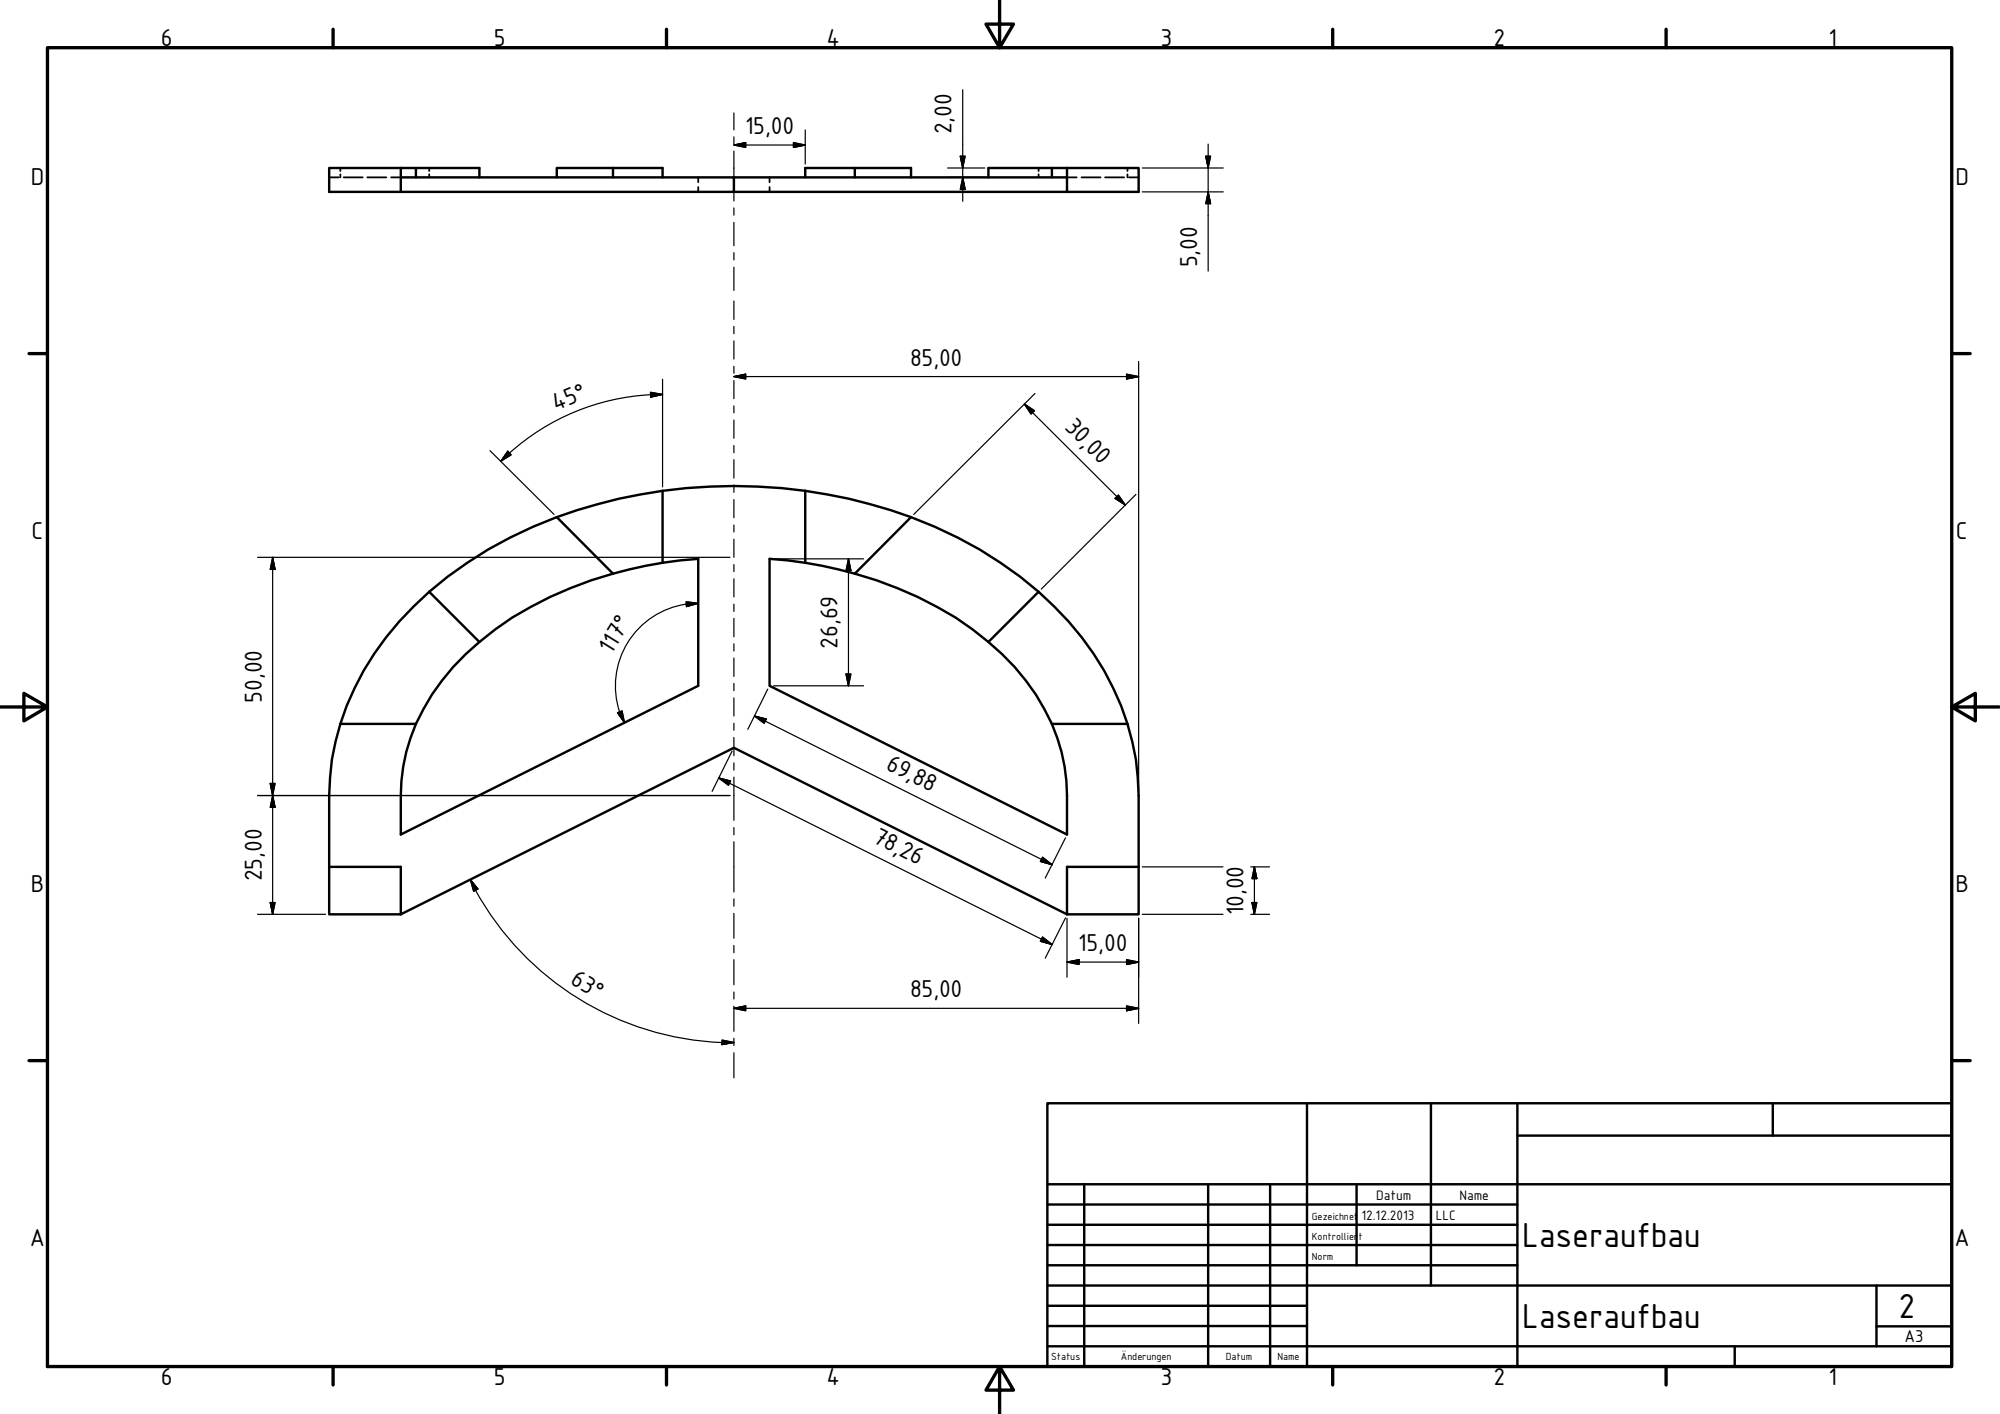
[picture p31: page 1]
eic; lie

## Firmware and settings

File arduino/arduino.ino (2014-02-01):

#include "pitches.h"
#include <Servo.h>
#include <SharpIR.h>

#include "serial_cmd.h"

//pins and constants
#define LASER_STEERING_FRONT 12
#define LASER_STEERING_BACK 4
#define MOTORS_I 7    //Digital-Steering
#define MOTORS_II 8   //Digital-Steering
#define MOTOR_I 5    //Propulsion FrontDir
#define MOTOR_II 6  //Propulsion BackDir
#define SPEED_MOTOR_A 9//H-Bridge
//#define LASER_SENSOR_R A0  //Analog
//#define LASER_SENSOR_B A1 //Analog
//#define LASER_SENSOR_0 0
//#define LASER_SENSOR_1 1
//#define LASER_SENSOR_2 2
//#define LASER_SENSOR_3 3
//#define LASER_SENSOR_4 4
#define LASER_SENSOR_B 5
#define BEEP 13
#define YELLOW_LED 3
#define RED_LED 2

int melodyPower[]={NOTE_C5,0,NOTE_C5};
int durationsPower[]={8,8,8};

int melodyConnect[]={NOTE_C4,0,NOTE_C5};
int durationsConnect[]={8,8,8};

int melodyDisconnect[]={NOTE_C5,0,NOTE_C4};
int durationsDisconnect[]={8,8,8};

int melodyPathStart[]={NOTE_C5,NOTE_E5, NOTE_G5};
int durationsPathStart[]={4,4,4};

int melodyPathEnd[]={NOTE_C6,0,NOTE_C6};
int durationsPathEnd[]={8,8,2}; 



SharpIR backIR = SharpIR(GP2Y0A02YK,LASER_SENSOR_B);  //red
SharpIR frontIR0 = SharpIR(GP2Y0A02YK,0); 
SharpIR frontIR1 = SharpIR(GP2Y0A02YK,1); 
SharpIR frontIR2 = SharpIR(GP2Y0A02YK,2); 
SharpIR frontIR3 = SharpIR(GP2Y0A02YK,3); 
SharpIR frontIR4 = SharpIR(GP2Y0A02YK,4); 
Servo frontServo, backServo;
uint8_t serialData[5];



void setup()                    // run once, when the sketch starts
{
  //Basic setup
  Serial.begin(9600);// set up Serial library at 9600 bps
  frontServo.attach(LASER_STEERING_FRONT);
  backServo.attach(LASER_STEERING_BACK);
  pinMode(MOTOR_I, OUTPUT);
  pinMode(MOTOR_II, OUTPUT);
  pinMode(SPEED_MOTOR_A, OUTPUT);
  pinMode(YELLOW_LED,OUTPUT);
  pinMode(RED_LED,OUTPUT);
  pinMode(BEEP,OUTPUT);
  digitalWrite(SPEED_MOTOR_A, HIGH); 
  backServo.write(90);
  frontServo.write(90);
  //playMelody(melodyPower,durationsPower,sizeof(melodyPower));
}


void loop()
{
  serialData[0]=getNextByte();
  switch(serialData[0])
  {
    case CMD_DRIVE_STOP:
      drive(DIR_STOP);
      break;
    case CMD_DRIVE_FWD:
      drive(DIR_FWD);
      break;
    case CMD_DRIVE_RWD:
      drive(DIR_RWD);
      break;
    case CMD_STEER_LEFT:
      steer(LEFT);
      break;
    case CMD_STEER_STRAIGHT:
      steer(STRAIGHT);
      break;
    case CMD_STEER_RIGHT:
      steer(RIGHT);
      break;
    case CMD_MOVE_LASER_FRONT:
      frontServo.write(getNextByte());
      break;
    case CMD_MOVE_LASER_BACK:
      backServo.write(getNextByte());
      break;
    case CMD_GET_LASERDATA_FRONT:
      serialData[0]=frontIR0.getData();
      serialData[1]=frontIR1.getData();
      serialData[2]=frontIR2.getData();
      serialData[3]=frontIR3.getData();
      serialData[4]=frontIR4.getData();
      Serial.write(serialData,5);
      break;
    case CMD_GET_LASERDATA_BACK:
      Serial.write(backIR.getData());
      break;
    case CMD_RED_LED_ON:
      digitalWrite(RED_LED,HIGH);    
      //playMelody(melodyPathStart,durationsPathStart,sizeof(melodyPathStart));  
      break;
    case CMD_RED_LED_OFF:
      digitalWrite(RED_LED,LOW);      
      //playMelody(melodyPathEnd,durationsPathEnd,sizeof(melodyPathEnd));  
      break;
    case CMD_YELLOW_LED_ON:
      digitalWrite(YELLOW_LED,HIGH);      
      //playMelody(melodyConnect,durationsConnect,sizeof(melodyConnect));  
      break;
    case CMD_YELLOW_LED_OFF:
      digitalWrite(YELLOW_LED,LOW);      
      //playMelody(melodyConnect,durationsDisconnect,sizeof(melodyDisconnect));  
      break;
    default:
      break;
  }
}  



//set the driving direction. possible values: DIR_STOP, DIR_FWD, DIR_RWD
void drive(int dir){
  if(dir == DIR_STOP){
    digitalWrite(MOTOR_I, LOW);
    digitalWrite(MOTOR_II, LOW);
  }
  else if(dir == DIR_FWD){
    digitalWrite(MOTOR_I, HIGH);
    digitalWrite(MOTOR_II, LOW);
  }
  else if(dir == DIR_RWD){
    digitalWrite(MOTOR_I, LOW);
    digitalWrite(MOTOR_II, HIGH);
  }
}


//control steering. possible values: STRAIGHT, LEFT, RIGHT
void steer(byte dir){
 switch(dir)
  {
  case STRAIGHT:
     digitalWrite(MOTORS_I, LOW);
     digitalWrite(MOTORS_II, LOW);
     break;
   case RIGHT:
     digitalWrite(MOTORS_I, LOW);
     digitalWrite(MOTORS_II, HIGH);
     break;
   case LEFT:
     digitalWrite(MOTORS_I, HIGH);
     digitalWrite(MOTORS_II, LOW);
     break;
   default: break;
   } 
}


void playMelody(int* melody, int* durations, int size) {
  // iterate over the notes of the melody:
  for (int thisNote = 0; thisNote < size; thisNote++) {

    // to calculate the note duration, take one second 
    // divided by the note type.
    //e.g. quarter note = 1000 / 4, eighth note = 1000/8, etc.
    int noteDuration = 1000/durations[thisNote];
    tone(BEEP, melody[thisNote],noteDuration);

    // to distinguish the notes, set a minimum time between them.
    // the note's duration + 30% seems to work well:
    int pauseBetweenNotes = noteDuration * 1.30;
    delay(pauseBetweenNotes);
    // stop the tone playing:
    noTone(BEEP);
  }
}


//blocks until serial data is available and then returns the next byte.
uint8_t getNextByte()
{
  while(Serial.available()==0)
    {
    }//wait
  return Serial.read();
}

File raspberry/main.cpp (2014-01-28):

#include "observer.h"
#include <unistd.h>
#include "threads.h"

int main()
{
	uint8_t fd[5];
	std::string ps=PIPE_DESC;
	USBPipe p(&ps);
	rasp_sock::RaspberrySocket s;
	s.initSocket();
	
	Observer o(&s,&p);
	std::thread t1(socketThreadEntry,&s,&o.toArduino, &o);
	std::thread t2(pathFindingThread, &o);
	o.run();
	//sleep(10000);
	/*sleep(2);
	p.usbFlush();
	sleep(2);
	o.drive(DIR_FWD);
	sleep(1);
	o.steer(LEFT);	
	sleep(1);
	std::cout<<static_cast<int>(o.getBackDistance());
	sleep(1);
	o.getFrontDistance(fd);
	for(int i=0;i<5;i++)
		std::cout<<static_cast<int>(fd[i])<<' ';
	sleep(1);
	o.moveFrontLaser(70);
	sleep(1);
	o.moveFrontLaser(30);

	o.moveBackLaser(30);
	sleep(3);*/
	
	return 0;	
}

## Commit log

2013-11-18 Initial arduino version
2013-11-19 USBPipe
    Added USBPipe functionality to the raspberry stuff
2013-11-25 arduino src
2013-11-25 arduino code sensor range
2013-11-26 sensors working a bit better
2013-11-26 arduino fix
2013-11-29 Added Video and inserted it into the Presentation
2013-11-29 arduino: basic collision avoidance + cleanup + comments
    [arduino.ino]
2013-12-01 Video und Bilder hochladen
2013-12-03 added socket for raspberry
2013-12-03 Added speedcontrol (PWM)
2013-12-03 Added empty Arduino file
2013-12-10 Added Laser-Platform-Construction
    [Laseraufbau.ipt, Laseraufbau.stp]
2013-12-10 Added second servo
2013-12-10 Raspberry accesspoint configs + startscript
2013-12-12 merged raspberry branch
2013-12-16 arduino sketch for basic control over usb
2013-12-16 raspberry comm
2013-12-16 incomplete rpi<->arduino communication
2013-12-17 communication: compile fixes, typos etc, still segfault
    [communication.h, main.cpp]
2013-12-17 socket thread
2014-01-07 last comm fixes for ard<->rpi + test in main.cpp
    [main.cpp]
2014-01-09 fix for mobile blocking mode
    [communication.h, main.cpp]
2014-01-14 fotos and video of the 3D laser-case-print
2014-01-28 sensors added
2014-01-28 fix arduino
2014-01-28 leds on arduino added
2014-01-28 LEDs to raspberry added
2014-02-01 laser movement
